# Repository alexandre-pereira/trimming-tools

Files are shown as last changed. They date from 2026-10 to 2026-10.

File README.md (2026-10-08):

# Banc de calage parapente

[English version](README.en.md)

Pour vérifier le calage de sa voile, il faut mesurer chaque suspente sous la même tension.
Ici, deux pièces imprimées en 3D font le travail avec un télémètre laser et une poche à eau
de 5 L : un **banc** qui se pose sur le bord d'une table et tend la suspente à 5 kg, et un
**support de laser** qui coince la patte de la suspente côté voile. Quincaillerie : 30 €.

| Le banc, suspente tendue | Plié : 164 × 93 × 52 mm | Le support du laser et son encoche |
|---|---|---|
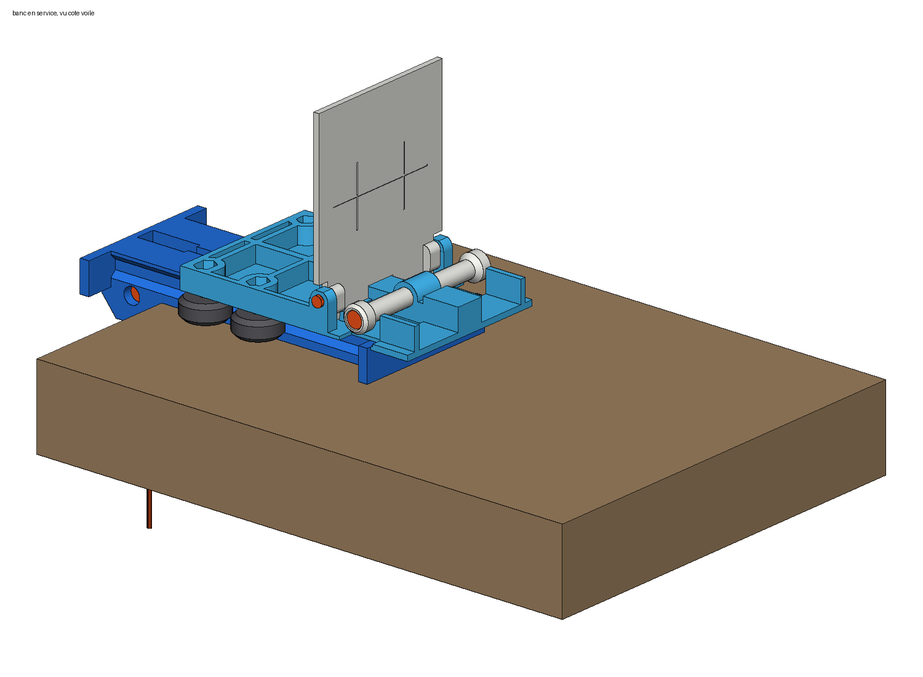
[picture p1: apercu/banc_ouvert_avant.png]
Le banc en service, vu du côté de la voile
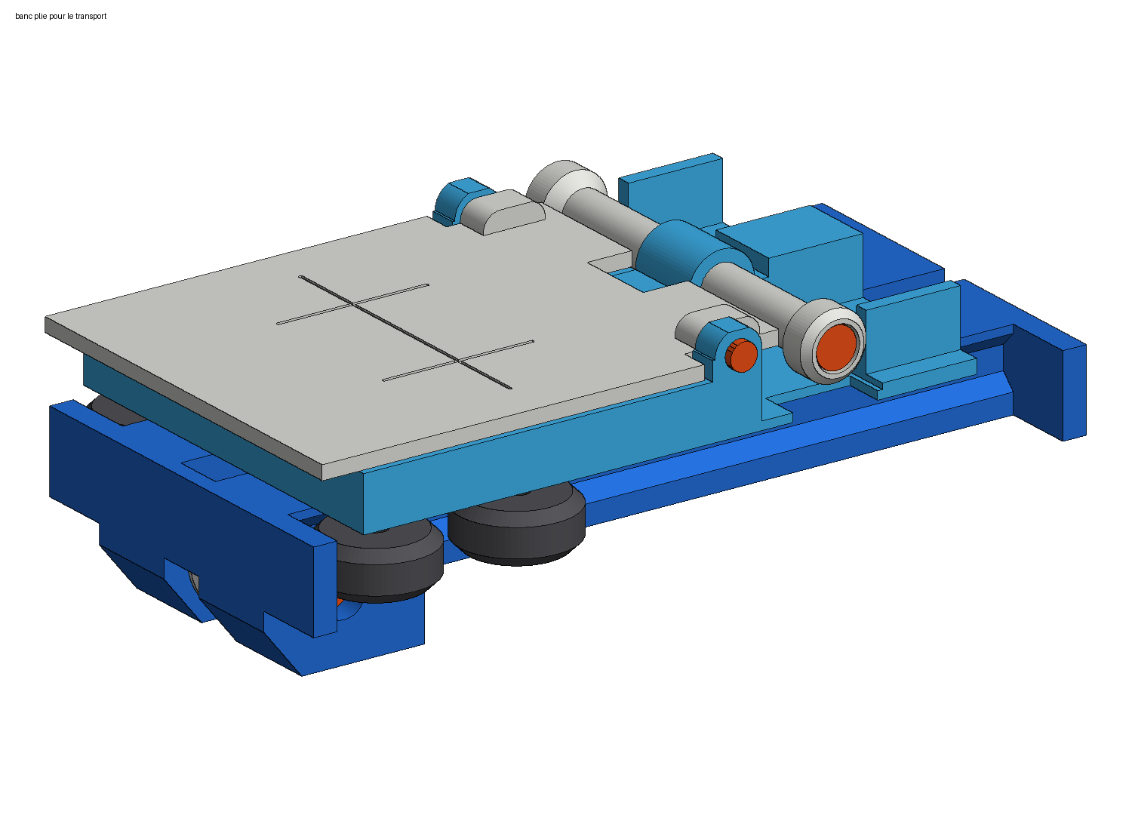
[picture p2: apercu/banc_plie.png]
Le banc plié pour le transport
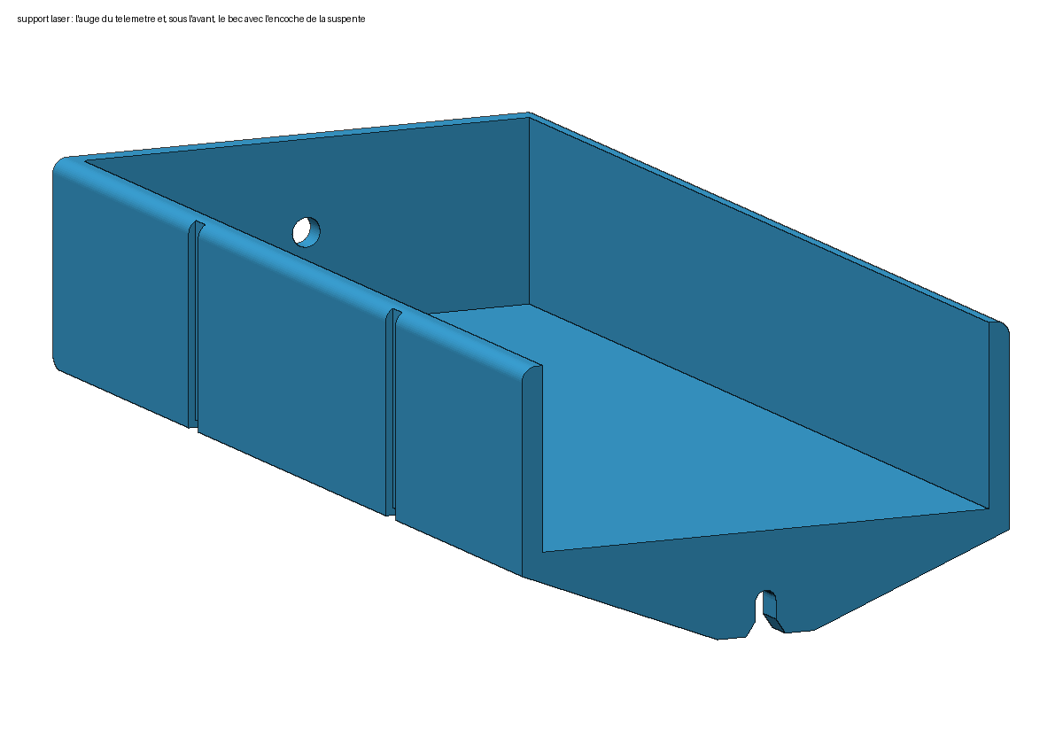
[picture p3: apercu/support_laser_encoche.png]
Le support du télémètre laser, avec l'encoche de la suspente sous l'avant
|  |  |  |

## Comment ça marche

- Le banc s'accroche au bord de la table. Les deux **élévateurs** se posent à plat dessus,
  chacun sur une bobine ; on passe simplement la boucle du maillon par-dessus.
- Un chariot à roulettes relie les élévateurs, par une cordelette et une poulie, à la **poche
  à eau** qui pend sous la table. Tant que le chariot flotte entre ses butées, la suspente est
  tendue à exactement 5 kg.
- Devant les élévateurs, une **cible blanche** se relève et se verrouille d'équerre.
- Côté voile, on glisse la suspente dans l'**encoche du support**, la patte vient en butée,
  et le laser couché dans le support vise la cible. L'outil de calage en ligne fait le reste,
  avec l'offset indiqué plus bas.
- Pour voyager : cible rabattue, un velcro autour.

## Fichiers à imprimer

Sept fichiers pour le banc, un par pièce, déjà orientés pour l'impression, sans support ;
puis le support du laser, dans la version de votre télémètre.

| Fichier | Pièce |
|---|---|
| `socle.stl` | le socle qui s'accroche à la table ([image](apercu/socle.png)) |
| `coulisseau.stl` | le chariot qui porte les élévateurs et la cible ([image](apercu/coulisseau.png)) |
| `cible.stl` | la cible, à imprimer en blanc ([image](apercu/cible.png)) |
| `poulie.stl` | la poulie de la cordelette ([image](apercu/poulie.png)) |
| `bobine_tete.stl`, `bobine_ecrou.stl` | les deux bobines des élévateurs ([image](apercu/bobine_tete.png)) |
| `entretoises_grappe.stl` | 8 petites entretoises sur une barrette, à détacher au cutter ([image](apercu/entretoises_grappe.png)) |

### Le support du laser, à la taille de votre télémètre

Même pièce ([l'encoche](apercu/support_laser_encoche.png), [vue de dessous](apercu/support_laser_bec.png)),
une version par télémètre : les Leica DISTO et les Bosch à moins de 500 €, aux cotes du
constructeur plus 0,5 mm de jeu. Le support est 3 mm moins haut que le télémètre, pour le
saisir et atteindre ses boutons. Certains télémètres ne mesurent que depuis leur face
arrière : leur lecture est plus longue de leur propre longueur, le tableau dit combien
retrancher. GLM 100, 120 et 150 : pointe arrière rentrée.

<!-- supports:debut -->
| Télémètre | Cotes constructeur (mm) | Repère de mesure | Fichier |
|---|---|---|---|
| Leica DISTO D1 | 115 × 43.5 × 23.5 | arrière seulement : retranchez 115 mm de la lecture | `support_laser_leica_d1.stl` ([image](apercu/support_laser_leica_d1.png)) |
| Leica DISTO D110 / E7100i | 120 × 37 × 23 | arrière seulement : retranchez 120 mm de la lecture | `support_laser_leica_d110.stl` ([image](apercu/support_laser_leica_d110.png)) |
| Leica DISTO D2 (v1, 100 m) | 116 × 44 × 26 | avant ou arrière | `support_laser_leica_d2_v1.stl` ([image](apercu/support_laser_leica_d2_v1.png)) |
| Leica DISTO D2 (2025, 150 m) / D2G | 127 × 50.5 × 24.5 | avant ou arrière | `support_laser_leica_d2_2025.stl` ([image](apercu/support_laser_leica_d2_2025.png)) |
| Leica DISTO X1 | 125 × 53.5 × 25.5 | arrière seulement : retranchez 125 mm de la lecture | `support_laser_leica_x1.stl` ([image](apercu/support_laser_leica_x1.png)) |
| Leica DISTO X3 / X4 | 132 × 56 × 29 | avant ou arrière | `support_laser_leica_x3_x4.stl` ([image](apercu/support_laser_leica_x3_x4.png)) |
| Bosch GLM 40 / GLM 30 | 105 × 41 × 24 | avant ou arrière | `support_laser_bosch_glm40.stl` ([image](apercu/support_laser_bosch_glm40.png)) |
| Bosch GLM 50-22 / 50-25 G / 50-27 C / 50-27 CG / 40-31 | 119 × 53 × 29 | avant ou arrière | `support_laser_bosch_glm50.stl` ([image](apercu/support_laser_bosch_glm50.png)) |
| Bosch GLM 80 | 111 × 51 × 30 | avant ou arrière | `support_laser_bosch_glm80.stl` ([image](apercu/support_laser_bosch_glm80.png)) |
| Bosch GLM 100-25 C / 150-27 C / 120 C | 142 × 64 × 28 | avant ou arrière | `support_laser_bosch_glm100_150.stl` ([image](apercu/support_laser_bosch_glm100_150.png)) |
| Bosch Zamo (IV, 2025) | 104 × 38 × 23 | arrière seulement : retranchez 104 mm de la lecture | `support_laser_bosch_zamo.stl` ([image](apercu/support_laser_bosch_zamo.png)) |
| Bosch PLM30-21 / EasyDistance 20 | 94 × 36 × 23 | arrière seulement : retranchez 94 mm de la lecture | `support_laser_bosch_plm30.stl` ([image](apercu/support_laser_bosch_plm30.png)) |
| Bosch PLM40-23 / 50-23 / 60-23C / 70-23C, UniversalDistance 30 / 40C / 50 / 50C, PLR 30 C / 40 C | 100 × 42 × 22 | avant ou arrière | `support_laser_bosch_plm40_70.stl` ([image](apercu/support_laser_bosch_plm40_70.png)) |
| Bosch PLM70-27 / AdvancedDistance 50C / PLR 50 C | 115 × 50 × 23 | avant ou arrière | `support_laser_bosch_plm70_27.stl` ([image](apercu/support_laser_bosch_plm70_27.png)) |
<!-- supports:fin -->

Autre télémètre : mesurez-le (largeur, longueur, épaisseur), reportez les trois cotes dans
`scad/support_laser.scad` et regénérez le STL ; `btn_cote` ouvre une paroi en face de boutons
latéraux.

## Quelle matière

**PETG**, 4 périmètres, 25 % de remplissage, cible en blanc mat. Pas de PLA : il se déforme
dans une voiture au soleil.

Si vous faites imprimer chez [JLC3DP](https://jlc3dp.com/3d-printing-quote) : tout en
**nylon SLS 3201PA-F**, sauf la cible en **résine SLA 9000HE** blanche. Comptez ≈ 44 $ de
pièces pour le banc et ≈ 10 $ de port. Les pièces serrées par des vis ou tirées par
une suspente (socle, chariot, support du laser) ne doivent pas être en résine : elle casse
au lieu de plier.

## Ce qu'il faut acheter

Rien que des vis et des écrous frein, tous sur AliExpress, chez des vendeurs notés. Prix lus
le 5 octobre 2026 (vis M5 × 40, vis et écrous M3 : le 8) ; vérifiez la variante cochée avant
de payer.

| Pièce | Variante à cocher | Il en faut | Prix | Lien |
|---|---|---|---|---|
| Roues V noires Ø 24, roulements montés | « 10PC BigBlack Wheel » | 5 sur 10 | 6,69 € | [annonce](https://fr.aliexpress.com/item/1005003090749056.html) |
| Vis M5 × 25 tête bombée (roues) | « 10Pcs M5x25 » | 4 sur 10 | 4,29 € | [annonce](https://fr.aliexpress.com/item/32850409234.html) |
| Vis M3 × 12 tête bombée (charnière de la cible) | « 30Pcs M3x12 » | 2 sur 30 | 3,69 € | [même annonce](https://fr.aliexpress.com/item/32850409234.html) |
| Vis M5 × 80 tête cylindrique (bobines) | « M5 10 pièces », puis « 80 mm » | 1 sur 10 | 5,09 € | [annonce](https://fr.aliexpress.com/item/32968483467.html) |
| Vis M5 × 40 tête cylindrique (axe de la poulie) | « M5 10 pièces », puis « 40 mm » | 1 sur 10 | 3,09 € | [même annonce](https://fr.aliexpress.com/item/32968483467.html) |
| Écrous frein M5 à bague nylon | « M5 X 50pcs » | 6 sur 50 | 3,39 € | [annonce](https://fr.aliexpress.com/item/1005002375633274.html) |
| Écrous frein M3 à bague nylon | « M3 X 50pcs » | 2 sur 50 | 2,26 € | [même annonce](https://fr.aliexpress.com/item/1005002375633274.html) |
| Cordelette 2 mm | « 10 meters » | 1,5 m | 1,62 € | [annonce](https://fr.aliexpress.com/item/1005011930498059.html) |

**≈ 30 € port compris.** Le roulement de la poulie se récupère sur la cinquième roue, le lest
est votre poche à eau, et il n'y a ni colle ni frein-filet : tout se visse dans des trous
de passage, avec un écrou frein au bout. Le laser n'est pas compté :
un télémètre Bluetooth de 30 m (HOTO QWCJY001 ou équivalent) vaut 30 à 40 €.

### La même chose en Europe

Toute la visserie se trouve à l'unité chez visseriefixations.fr (France). Aucun des sites
européens examinés n'a aussi les roues : elles viennent d'une boutique d'impression 3D. Prix
lus le 8 octobre 2026, port non compris (il ne s'affiche que dans le panier).

| Pièce | Référence du site | Il en faut | Prix | Lien |
|---|---|---|---|---|
| Roues V Ø 24 × 10 en POM, alésage 5, roulements 625ZZ montés | lot de 6 | 5 sur 6 | 12,90 € | [3delectroshop.fr](https://3delectroshop.fr/roulements-et-rotules/504-roulettes-v-slot-en-pom-avec-roulements-625zz.html) |
| Vis M5 × 25 tête bombée, ISO 7380, inox A2 (roues) | TBHC05/025A2 | 4 | 0,08 € pièce | [visseriefixations.fr](https://www.visseriefixations.fr/vis-a-six-pans-creux/tete-bombee-hexagonale-creuse/tbhc-inox-a2-iso-7380/tbhc-m5x25-inox-a2-iso-7380.html) |
| Vis M3 × 12 tête bombée, ISO 7380, inox A2 (charnière de la cible) | TBHC03/012A2 | 2 | 0,05 € pièce | [visseriefixations.fr](https://www.visseriefixations.fr/vis-a-six-pans-creux/tete-bombee-hexagonale-creuse/tbhc-inox-a2-iso-7380/tbhc-m3x12-inox-a2-iso-7380.html) |
| Vis M5 × 40 tête cylindrique, DIN 912, inox A2 (axe de la poulie) | TCHC05/040A2PF | 1 | 0,13 € | [visseriefixations.fr](https://www.visseriefixations.fr/vis-a-six-pans-creux/tete-cylindrique-hexagonale-creuse/inox-a2/tchc-inox-a2-filetage-partiel-din-912/tchc-m5x40-inox-a2-pf-din-912.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) |
| Écrous frein M3 à bague nylon, DIN 985, inox A2 | ECRNYL03A2 | 2 | 0,04 € pièce | [visseriefixations.fr](https://www.visseriefixations.fr/ecrous/ecrous-autofreines/ecrou-hexagonal-autofreine-nylstop/ecrou-nylstop-inox-a2-din-985/ecrou-nylstop-m3-inox-a2-din-985-17062-17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) |
| Écrous frein M5 à bague nylon, DIN 985, inox A2 | ECRNYL05A2 | 6 | 0,04 € pièce | [visseriefixations.fr](https://www.visseriefixations.fr/ecrous/ecrous-autofreines/ecrou-hexagonal-autofreine-nylstop/ecrou-nylstop-inox-a2-din-985/ecrou-nylstop-m5-inox-a2-din-985-99867-99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) |
| Vis M5 × 80 tête cylindrique, DIN 912, inox A2 (bobines) | TCHC05/080A2PF | 1 | 0,59 € | [visseriefixations.fr](https://www.visseriefixations.fr/vis-a-six-pans-creux/tete-cylindrique-hexagonale-creuse/inox-a2/tchc-inox-a2-filetage-partiel-din-912/tchc-m5x80-inox-a2-pf-din-912.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) |

**Visserie : 1,46 €, plus le port ; roues : 12,90 €, plus le port.** La cordelette est
n'importe quelle cordelette de 2 mm.

## Montage

Le schéma complet, avec la visserie : [schema_montage.png](apercu/schema_montage.png).

1. **Poulie** : sortez un roulement d'une roue en trop, emmanchez-le dans la poulie. Posez la
   poulie dans sa fente avec une entretoise de chaque côté. Glissez un écrou frein M5 dans son
   logement, sur un flanc du socle, passez la vis M5 × 40 par l'autre flanc et vissez (clé
   Allen de 4) jusqu'à ce que la tête porte, sans forcer. Tête et écrou restent sous les
   flancs.
2. **Roues** : un écrou frein dans chacun des 4 logements du chariot, puis pour chaque roue
   une vis M5 × 25 par le dessous, à travers la roue et une entretoise.
3. **Jeu** : serrez le côté fixe, poussez les deux autres roues au fond de leur rainure (trous
   oblongs), serrez. Le chariot doit rouler tout seul quand on incline le socle.
4. **Bobines** : sur la vis M5 × 80, une bobine, la nervure du chariot, l'autre bobine, l'écrou
   frein dans le chapeau. On n'y touche plus.
5. **Cible** : glissez un écrou frein M3 dans le logement de chaque oreille du chariot, côté
   intérieur, puis présentez la cible entre les oreilles : elle retient les écrous. De chaque
   côté, vissez une vis M3 × 12 à travers l'oreille (clé Allen de 2) jusqu'à ce que sa tête
   porte. Le bout de la vis sert d'axe à la cible.
6. **Cordelette** : nœud en huit dans le puits derrière la cible ; le brin file dans le canal
   du socle, passe sur la poulie et se noue à la poignée de la poche. Pesez la poche pleine à
   **5,00 kg**.

Réglez la cordelette pour que la poche touche le sol quand la suspente est molle, et décolle
dès qu'on tire.

## Régler l'offset dans l'outil de calage

L'outil demande la distance entre le point d'accrochage de l'élévateur et la cible. Sur le
banc, l'élévateur entier est pris sur la bobine : l'axe de sa vis est à **21 mm** de la face
de la cible, du côté du laser.

**Offset à saisir : 21 mm.**

Réglez le télémètre pour mesurer **depuis sa face avant** : elle affleure le bec du support.

## Pour aller plus loin

- [NOTES.md](https://github.com/alexandre-pereira/trimming-tools/blob/main/NOTES.md) : les
  choix de conception, les cotes, les prix relevés, les variantes écartées et ce qui a été
  vérifié.
- Les modèles OpenSCAD sont dans `scad/`, les scripts qui regénèrent STL, images et ce site
  dans `outils/`. Dépôt : <https://github.com/alexandre-pereira/trimming-tools>, site : <https://trimming-tools.wesoar.fr>.
- Rien n'a encore été imprimé ni essayé sous charge : c'est un modèle, pas un produit testé.

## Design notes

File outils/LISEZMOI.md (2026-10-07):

# Outils de génération

Scripts qui produisent les STL, les images d'aperçu et les schémas de montage.
OpenSCAD n'a pas besoin d'être installé : le rendu passe par sa version WebAssembly.

À lancer depuis ce dossier :

```
npm install openscad-wasm-prebuilt     # une seule fois
node generer_stl.mjs                   # STL dans ../stl, pièces d'assemblage dans ./asm, contrôles d'interférence
python render2.py                      # une image par STL + vues d'assemblage, dans ../apercu
python schema.py                       # schémas de montage avec la visserie, dans ../apercu
```

Python a besoin de `numpy` et `Pillow`. Les positions de la visserie dans `schema.py`
reprennent les cotes de `../scad/banc.scad` : si le modèle change, les mettre à jour.

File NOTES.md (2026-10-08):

# Notes de conception du banc de calage

Ce document rassemble le détail : choix de conception, cotes, prix relevés, vérifications,
variantes écartées. La présentation courte est dans [README.md](README.md).

Un petit bloc imprimé qui se pose sur le bord d'une table, sur le principe de l'EasyTrim :
il met la suspente sous 5 kg et présente une cible au télémètre laser. La cible se rabat
à plat pour le transport.

| En service | Plié |
|---|---|
| banc ouvert | banc plié |

Autres vues : [côté poche à eau](apercu/banc_ouvert_arriere.png),
[profil ouvert](apercu/banc_ouvert_profil.png), [profil plié](apercu/banc_plie_profil.png).

## Principe

- Le **socle** s'accroche au chant de la table par deux crochets. Aucune fixation : c'est la
  tension de la suspente qui le plaque contre le bord.
- La **poulie** tourne sur un roulement à billes, autour d'une vis M5 qui traverse
  les deux crochets. Elle est logée dans le bloc des crochets, sous le passage du
  coulisseau : la cordelette monte de la poche à eau, passe sur la poulie et rejoint le
  coulisseau par un canal creusé dans le dessus du socle. Rien ne dépasse du socle, et les
  rainures des roues passent au-dessus des crochets : c'est ce qui rend le banc court.
- Les **fins de course** sont deux butées relevées aux deux bouts du socle, contre lesquelles
  les roues s'arrêtent. Le coulisseau ne peut pas sortir de ses rainures.
- Le **coulisseau** roule sur le socle par 4 roues à gorge en V montées sur des vis M5.
  Les roues s'engagent dans deux rainures en V taillées dans les flancs du socle : le
  coulisseau ne peut ni se soulever ni se mettre de travers.
- Les **élévateurs** s'accrochent à l'avant du coulisseau, posés à plat, chacun sur une
  bobine, de part et d'autre d'une nervure centrale. La boucle de base de l'élévateur se
  passe par-dessus le chapeau de la bobine, sans rien dévisser, puis la sangle se couche
  dans son couloir, entre la nervure et une joue : elle ne peut pas glisser de côté. Rien ne
  se démonte à l'usage, donc rien ne se perd, et la sangle ne touche que du plastique lisse
  (la vis qui porte les bobines est noyée dedans). La traction passe par tout l'élévateur,
  comme en vol.
- La **cible** est articulée à l'avant du coulisseau, juste derrière les bobines. Relevée et
  poussée vers le bas, sa languette se coince entre la face avant du coulisseau et une lèvre
  inclinée : elle est verrouillée d'équerre et ne peut basculer ni en avant ni en arrière.
  Pour la rabattre, on la soulève de 5,5 mm puis on la couche sur le coulisseau. Une mire
  gravée indique où viser.
- Côté voile, le **support du laser** coince la patte d'attache dans l'encoche de son bec, et
  le laser couché dedans vise la cible. **Longueur = lecture + constante**, la constante
  étant étalonnée une fois.

Quand le coulisseau flotte entre ses deux butées, la suspente est tendue au poids de la
poche. Deux choses pourraient fausser cette tension, et le banc est dessiné pour les rendre
négligeables :

- **le frottement de la poulie** : elle tourne sur un roulement à billes, pas sur un simple
  axe (un axe lisse dans du plastique mangerait de l'ordre de 10 % de la tension, dans un
  sens puis dans l'autre) ;
- **l'inclinaison de la cordelette** : la poulie étant sous le coulisseau, le brin monte de
  6 mm jusqu'à son attache. Celle-ci est placée le plus en avant possible du coulisseau, si
  bien que la tension réelle vaut 99,2 % du poids en butée arrière, 99,8 % à mi-course et
  99,9 % en fin de course (calcul géométrique, non mesuré).

## Encombrement

| | Longueur | Largeur | Épaisseur |
|---|---|---|---|
| Plié | 164 mm | 93 mm | 52 mm (dont 14 mm de crochets) |
| En service | 164 mm, plus l'avancée du coulisseau | 93 mm | 136 mm |

Course du coulisseau : 100 mm. La longueur du banc vaut course + entraxe des roues + 34 mm
(un diamètre de roue et les deux butées de 5 mm) ; les 34 mm de crochets devant la table sont
compris, puisque les rainures passent au-dessus. On peut échanger course et entraxe dans
`banc.scad` :

| Entraxe des roues (`wheel_px`) | Course (`travel`) | Longueur du banc |
|---|---|---|
| **30 mm (réglage actuel)** | **100 mm** | **164 mm** |
| 40 mm | 100 mm | 174 mm |
| 30 mm | 150 mm | 214 mm |

Au repos et plié, tout tient dans la longueur du socle : le coulisseau (130 mm) reste
au-dessus, et la cible rabattue ne dépasse pas à l'arrière. En bout de course côté voile,
l'avant du coulisseau dépasse du socle de 75 mm, au-dessus de la table.

L'entraxe de 30 mm est le plus court raisonnable : en dessous de 28 mm, les roues se
toucheraient. Un entraxe court guide un peu moins bien le coulisseau quand un seul élévateur
tire, donc de travers ; si cela se voit à l'usage, repasser à 40 mm coûte 10 mm de longueur.

Deux variantes plus courtes ont été essayées puis écartées :

- 149 mm, roues fixées sur le socle et coulisseau en tiroir : plus épaisse de 8 mm,
  coulisseau en deux pièces qui dépasse derrière la table au repos. Son modèle reste dans
  `scad/banc_149mm.scad`, sans STL.
- 146 mm, sans butées en bout de socle, le coulisseau étant arrêté par une goupille circulant
  dans le canal de la cordelette. Non conservée.

## Pièces imprimées (`stl/`)

| Fichier | Pièce | Aperçu | Volume |
|---|---|---|---|
| `socle.stl` | socle, butées, crochets de table, logement de la poulie, canal de la cordelette | [image](apercu/socle.png) | 101 cm³ |
| `coulisseau.stl` | plaque mobile, couloirs des élévateurs, lèvre de verrouillage, oreilles de charnière | [image](apercu/coulisseau.png) | 58 cm³ |
| `poulie.stl` | poulie Ø25, avec le logement du roulement 625 | [image](apercu/poulie.png) | 2 cm³ |
| `cible.stl` | cible articulée 84 × 101, avec mire gravée | [image](apercu/cible.png) | 25 cm³ |
| `bobine_tete.stl` | bobine dont le chapeau loge la tête de vis | [image](apercu/bobine_tete.png) | 2 cm³ |
| `bobine_ecrou.stl` | bobine dont le chapeau loge l'écrou frein | [image](apercu/bobine_ecrou.png) | 2 cm³ |
| `entretoises_grappe.stl` | les 8 entretoises (4 pour les roues, 2 pour la poulie, 2 de rechange) réunies par une barrette, à détacher au cutter | [image](apercu/entretoises_grappe.png) | 1 cm³ |
| `support_laser_<modèle>.stl` | support du télémètre, côté voile, avec son bec à encoche ; une version par télémètre | [en service](apercu/support_laser_arriere.png), [le bec](apercu/support_laser_bec.png) | ≈ 20 à 50 cm³ |

Une pièce par fichier, chaque fichier à imprimer une fois ; seules les entretoises sont
groupées, parce qu'un service d'impression refuse les pièces minuscules.

Toutes sortent orientées pour l'impression, sans support : socle dessus contre le plateau,
coulisseau dessous contre le plateau, cible dos contre le plateau, poulie à plat, bobines
debout sur leur tube, entretoises à plat, support du laser debout sur la face avant de son
bec.

Pour un objet qui voyage : PETG (ou ASA), 4 périmètres, 25 % de remplissage. Cible en blanc
mat de préférence.

Les modèles paramétriques sont `scad/banc.scad` (variable `part` pour choisir la pièce,
`plie = true` pour voir l'assemblage rabattu) et `scad/support_laser.scad`.

## Support du laser

Repris de votre « TEST.stl », même principe : le télémètre est couché dans une auge ouverte
à l'avant ; sous l'avant, un bec plat descend sous le fond et porte une encoche. On y glisse
la suspente par en dessous, sa patte d'attache (ou son nœud), trop grosse, bute contre le
bec : sous 5 kg, la suspente reste dans l'axe du faisceau. Vues :
[en service, vu de l'arrière](apercu/support_laser_arriere.png), [le bec](apercu/support_laser_bec.png).

- **Cotes du télémètre en paramètres** : `laser_w`, `laser_l`, `laser_h` (largeur, longueur,
  épaisseur), à mesurer au pied à coulisse. Les valeurs par défaut (34,5 × 78,5 × 18 mm) sont
  celles de votre TEST.stl, pas celles d'un télémètre précis : les remplacer par les vôtres.
- **Moins épais que le télémètre** : les parois s'arrêtent `moins_epais` (3 mm) sous le dessus
  du télémètre, pour le saisir et atteindre ses boutons.
- **Boutons sur le côté** : `btn_cote` (0 aucun, 1 droite, -1 gauche, 2 les deux) abaisse la
  paroi en face des boutons, entre `btn_y0` et `btn_y0 + btn_len` depuis la face arrière du
  télémètre, en ne laissant que `btn_h` (4 mm) de paroi.
- **Encoche** : 3 mm de large (`slit_w`), entrée en V, fond rond : toutes les suspentes
  passent, la patte d'attache ou son nœud non. Le bec garde la forme et l'épaisseur (4 mm)
  de TEST.stl ; une première version avec une bande de renfort derrière le bec a été
  retirée le 7 octobre 2026 : elle débordait sous le fond.
- **Offset** : l'outil de calage attend la distance entre l'axe d'accrochage de l'élévateur
  et la cible. L'élévateur entier est pris sur la bobine ; la face visée de la cible
  (`sl_front + tg_t` = 51) est 21 mm derrière l'axe des bobines (`sl_front + pin_x` = 72),
  vu du laser. Offset = 21 mm, le télémètre réglé « mesure depuis l'avant » (sa face avant
  affleure le bec, au jeu `fit` près).
- **Versions** : une par télémètre de `outils/lasers.json` (Leica DISTO et Bosch à moins de
  500 €, cotes constructeur) ; `node outils/generer_stl.mjs lasers` regénère les STL et le
  tableau du README.
- Deux rainures pour un élastique qui tient le télémètre, un trou de dragonne dans la face
  arrière, 21 cm³.

**Matière recommandée : PETG** (ou ASA) sur votre imprimante ou au fablab, 4 périmètres,
25 % de remplissage, comme le reste du banc. Chez JLC3DP : **nylon 3201PA-F**. Pas de résine
pour cette pièce : le bec travaille en tension et prend des chocs, et la résine casse au
lieu de plier.

## Ce qu'il faut acheter

Prix indicatifs relevés en ligne ou estimés ; à vérifier au moment de la commande.

| Pièce et dimensions | Qté (1 banc / 10) | Prix relevé | Lien |
|---|---|---|---|
| Roue V pour profilé V-slot, POM, Ø 24 × 10,2 mm, alésage 5 mm, 2 roulements 625ZZ montés | 4 / 40 | 12,90 € le lot de 6 | [3delectroshop.fr](https://3delectroshop.fr/roulements-et-rotules/504-roulettes-v-slot-en-pom-avec-roulements-625zz.html) ; par lots : [AliExpress](https://fr.aliexpress.com/item/1005001588321075.html) |
| Vis à tête bombée six pans creux M5 × 25, ISO 7380, filetée sur toute la longueur, tête Ø 9,5 × 2,75 mm, clé de 3 (roues) | 4 / 40 | 0,08 € pièce | [visseriefixations.fr](https://www.visseriefixations.fr/vis-a-six-pans-creux/tete-bombee-hexagonale-creuse/tbhc-inox-a2-iso-7380/tbhc-m5x25-inox-a2-iso-7380.html) |
| Roulement à billes 625ZZ, 5 × 16 × 5 mm (poulie) | 1 / 10 | 0 € pour un banc : le prendre sur une des 2 roues en trop du lot de 6 ; sinon 1,10 € pièce | [reprap-france.com](https://www.reprap-france.com/produit/1234568282-roulement-a-billes-625zz) |
| Vis à tête cylindrique six pans creux M5 × 40, DIN 912, tête Ø 8,5 × 5 mm, clé de 4, tige lisse sur ≈ 18 mm (axe de poulie) | 1 / 10 | 0,13 € pièce | [visseriefixations.fr](https://www.visseriefixations.fr/vis-a-six-pans-creux/tete-cylindrique-hexagonale-creuse/inox-a2/tchc-inox-a2-filetage-partiel-din-912/tchc-m5x40-inox-a2-pf-din-912.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) |
| Vis à tête cylindrique six pans creux M5 × 80, DIN 912, tête Ø 8,5 × 5 mm, clé de 4 (bobines) | 1 / 10 | 0,59 € pièce | [visseriefixations.fr](https://www.visseriefixations.fr/vis-a-six-pans-creux/tete-cylindrique-hexagonale-creuse/inox-a2/tchc-inox-a2-filetage-partiel-din-912/tchc-m5x80-inox-a2-pf-din-912.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) |
| Écrou frein à bague nylon M5, DIN 985, 8 mm sur plats, hauteur 5 mm (roues, bobines et poulie) | 6 / 60 | 0,04 € pièce | [visseriefixations.fr](https://www.visseriefixations.fr/ecrous/ecrous-autofreines/ecrou-hexagonal-autofreine-nylstop/ecrou-nylstop-inox-a2-din-985/ecrou-nylstop-m5-inox-a2-din-985-99867-99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) |
| Vis à tête bombée six pans creux M3 × 12, ISO 7380, tête Ø 5,7 × 1,65 mm, clé de 2 (charnières) | 2 / 20 | 0,05 € pièce | [visseriefixations.fr](https://www.visseriefixations.fr/vis-a-six-pans-creux/tete-bombee-hexagonale-creuse/tbhc-inox-a2-iso-7380/tbhc-m3x12-inox-a2-iso-7380.html) |
| Écrou frein à bague nylon M3, DIN 985, 5,5 mm sur plats, hauteur 4 mm (charnières) | 2 / 20 | 0,04 € pièce | [visseriefixations.fr](https://www.visseriefixations.fr/ecrous/ecrous-autofreines/ecrou-hexagonal-autofreine-nylstop/ecrou-nylstop-inox-a2-din-985/ecrou-nylstop-m3-inox-a2-din-985-17062-17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) |
| Cordelette Ø 2 mm, longueur 1,5 m | 1 / 10 | 0 € | reste de suspente, drisse, paracorde |
| Lest de 5 kg | 1 / — | 0 € | votre poche à eau, ou un bidon d'eau de 5 L à poignée |
| Sangle velcro 20 mm | — | 0 € | fonds de tiroir |
| **Visserie d'un banc** | | **1,46 €, hors port** | |
| Impression des 7 fichiers du banc et du support (≈ 210 cm³, ≈ 130 g de PETG ; plus grande pièce 164 × 80 × 31 mm) | 1 / 10 | 5–25 € | fablab, ou [devis JLC3DP](https://jlc3dp.com/3d-printing-quote) |
| Télémètre Bluetooth HOTO QWCJY001, 99,5 × 44,1 × 23,3 mm, 30 m, ±2 mm | 1 | 35–39 € | [ulen.eu](https://ulen.eu/fr/product/hoto-qwcjy001-telemetre-laser-bluetooth/), [domotique-store.fr](https://www.domotique-store.fr/maison/outillage/4240-metre-laser-intelligent-bluetooth-hoto-qwcjy001.html), [AliExpress](https://www.aliexpress.com/i/1005002004493544.html) |

Prix relevés sur les pages produit le 4 octobre 2026, ceux de la visserie et des roues relus
le 8 ; les frais de port ne sont pas vérifiés (ils ne s'affichent que dans le panier).
Le lot de 5 roues d'aboutfilament.fr (8,49 €) était en rupture le 4 ; celui de
3delectroshop.fr était en stock le 8 (4 lots).

**Toute la visserie sur un seul site européen : visseriefixations.fr**, à l'unité, sans
minimum de commande affiché. Recherche du 8 octobre 2026 sur une douzaine de sites :

- **Aucun des sites examinés n'a à la fois les roues V et la visserie à l'unité.** Il faut
  deux commandes.
- **bricovis.fr** a les mêmes références aux mêmes prix : c'est l'équivalent exact.
- **vis-express.fr** a tout aussi, nettement plus cher.
- Stock immédiat lu le 8 octobre : 350 vis M5 × 40 et 7 898 écrous frein M3 ; celui des vis
  M3 × 12 ne s'est pas affiché.
- La vis M5 × 25 peut y être livrée en filetage total ou partiel, la norme ne le fixant
  pas : les deux conviennent, l'écrou est au bout. La M5 × 80 n'existe qu'en filetage partiel
  (≈ 22 mm), ce qui convient aussi.
- Autre source de roues : roboter-bausatz.de, lot de 5 à 7,39 € (Ø 23,89 × 10,23, roulements
  625ZZ), mais 14,99 € de port vers la France.

Le chemin le moins cher : roues sur AliExpress (≈ 3 €), la visserie à l'unité en
quincaillerie (≈ 4 €), impression dans un fablab (≈ 5 €), cordelette et lest de récupération,
soit **≈ 12 € de banc**, plus le télémètre (≈ 25 € en promotion).

Ce qui a fait baisser la facture :

- **Le roulement de la poulie ne coûte rien** pour un seul banc : les roues se vendent par
  lot de 6, il en reste deux, et chacune contient deux roulements 625 qui se chassent à la
  main ou avec une vis.
- **L'axe de poulie est une vis M5 × 40** et son écrou frein, noyés dans les crochets.
- **Plus aucune rondelle à acheter** : les rondelles M5 sont remplacées par 6 entretoises
  imprimées (4 pour les roues, 2 pour la poulie), fournies dans `entretoises_grappe.stl` avec
  deux de rechange ; la
  rondelle M4 du nœud est supprimée.
- **Charnière sur deux vis M3 × 12** et leurs écrous frein, et **bobines sans rondelle**.
- **Ni colle ni frein-filet** : partout une vis dans un trou de passage et un écrou frein
  au bout.
- **Pas de mousqueton ni de Dyneema neuve** : n'importe quelle cordelette de 2 mm tient 5 kg ;
  elle se noue directement à la poignée du lest.
- **Lest** : la poche à eau que vous avez déjà, ou un bidon d'eau du commerce.
- **Socle évidé** par-dessous.

Ce qui reste cher, et pourquoi je n'y ai pas touché :

- **Le télémètre** pèse plus que tout le banc. Je n'ai pas trouvé de modèle Bluetooth vérifié
  moins cher que le HOTO ; les modèles à 12–18 € n'ont pas le Bluetooth. Il est vu de
  21 $ (promotion Amazon aux États-Unis) à 38 $ sur AliExpress : surveiller les promotions.
- **L'impression par un service en ligne** : c'est le port, plus que le plastique, qui fait
  le prix. Un fablab ou une imprimante prêtée ramène ce poste à ≈ 5 €.

### Tout acheter sur AliExpress : annonces qui ont des avis

Relevé du 5 octobre 2026 (vis M5 × 40, vis et écrous M3 : du 8). Pour chaque annonce, j'ai lu la note, le nombre
d'avis et les variantes que les acheteurs ont notées. **Vérifiez sur la page que la taille
existe et notez le prix** avant de commander.

| Pièce | Variante à choisir | Qté pour 1 banc | Avis | Lien |
|---|---|---|---|---|
| Roue V noire en POM, Ø 23,9 × 10,23 mm, alésage 5 mm, avec ses 2 roulements 625 | « 10PC BigBlack Wheel » (lot de 10) | 5 (4 roues + 1 pour le roulement de la poulie) | 4,9 / 5 sur 88 avis, dont 46 sur cette variante | [roues, lot de 10](https://fr.aliexpress.com/item/1005003090749056.html) |
| Vis à tête bombée six pans creux ISO 7380, inox, M5 × 25 (roues) | « 10Pcs M5x25 » | 4 | 4,8 / 5 sur 64 avis, dont 2 sur cette variante | [vis tête bombée M3 à M5](https://fr.aliexpress.com/item/32850409234.html) |
| Vis à tête bombée six pans creux ISO 7380, inox, M3 × 12 (charnières) | « 30Pcs M3x12 » | 2 | même annonce, 3 avis sur cette variante | [vis tête bombée M3 à M5](https://fr.aliexpress.com/item/32850409234.html) |
| Vis à tête cylindrique six pans creux DIN 912, inox 304, M5 × 80 (bobines) | « M5 10 pièces », longueur « 80 mm » | 1 | 4,9 / 5 sur 1 535 avis | [vis DIN912 HZYUEGOU](https://fr.aliexpress.com/item/32968483467.html) |
| Vis à tête cylindrique six pans creux DIN 912, inox 304, M5 × 40 (axe de poulie) | « M5 10 pièces », longueur « 40 mm » | 1 | même annonce, 5 avis sur cette variante parmi les 400 derniers | [vis DIN912 HZYUEGOU](https://fr.aliexpress.com/item/32968483467.html) |
| Écrou frein à bague nylon DIN 985, inox 304, M5 | « M5 X 50pcs » | 6 | 5,0 / 5 sur 22 avis, dont 3 sur cette variante | [écrous frein M2 à M20](https://fr.aliexpress.com/item/1005002375633274.html) |
| Écrou frein à bague nylon DIN 985, inox 304, M3 | « M3 X 50pcs » | 2 | même annonce, 5 avis sur cette variante | [écrous frein M2 à M20](https://fr.aliexpress.com/item/1005002375633274.html) |
| Cordelette de 2 mm (paracorde à une âme) | « 10 meters », couleur au choix | 1,5 m | 4,9 / 5 sur 108 avis | [paracorde 2 mm](https://fr.aliexpress.com/item/1005011930498059.html) |

Les goupilles des relevés précédents ont disparu de la liste : voir « Des vis et des écrous,
plus de goupilles ». Les trois lignes ajoutées viennent des annonces déjà retenues, donc sans
port supplémentaire.

La même liste, à cocher, est sur une page à part : <https://claude.ai/artifact/KuYeWNqA6emn3GKmHpZLea>
(page privée, ouverte avec votre compte Claude).

**Prix lus sur les annonces le 5 octobre 2026**, dans le navigateur, sans compte, pour une
livraison en France :

| Ligne | Prix lu |
|---|---|
| Roues « 10PC BigBlack Wheel », lot de 10 | 6,69 € |
| Vis M5 × 25 tête bombée, lot de 10 | 4,29 € |
| Écrous frein M5, lot de 50 | 3,39 € |
| Vis M5 × 80, lot de 10 | 5,09 € |
| Cordelette 2 mm, 10 m | 1,62 € |
| Vis M5 × 40, lot de 10 (lu le 8 octobre) | 3,09 € |
| Vis M3 × 12 tête bombée, lot de 30 (lu le 8 octobre) | 3,69 € |
| Écrous frein M3, lot de 50 (lu le 8 octobre) | 2,26 € |
| **Quincaillerie, tout compris** | **30,12 €**, livraison gratuite (articles « Choice », plus de 10 €) |

Une réserve :

- **Télémètre** : l'annonce HOTO que j'avais retenue n'est plus vendue en France (page
  introuvable). Une recherche montre un télémètre du même format à 29,39 €, noté 4,8, que je
  n'ai pas vérifié (marque, Bluetooth). Les revendeurs européens du tableau plus haut
  restent valables, à 35–39 €.

- **Roulement de la poulie** : il se prend sur la cinquième roue du lot de 10.
- **Sur les roues**, vérifiez à réception la largeur sur les deux roulements : le modèle
  compte 11 mm (paramètre `wheel_stack`).

### Prises de filet vérifiées

Calculées sur le modèle, vis par vis.

| Vis | Empilage sous la tête | Écrou | Bout de la vis |
|---|---|---|---|
| M5 × 25 des roues (×4), filetée sur toute la longueur | roue 11,0 (sur ses deux roulements) + entretoise 2,7 + coulisseau 5,3 = 19,0 mm | frein de 5 mm : de 19,0 à 24,0 | dépasse l'écrou de 1 mm (bague nylon en prise), reste 0,2 mm sous le dessus du coulisseau |
| M5 × 80 des bobines (×1) | bobine 29,25 + nervure 16 + bobine 28,25 = 73,5 mm | frein de 5 mm : de 73,5 à 78,5 | dépasse l'écrou de 1,5 mm (bague nylon en prise), reste 0,5 mm à l'intérieur du chapeau |
| M5 × 40 de la poulie (×1) | d'un fond de logement à l'autre : 50 − 9,5 − 6,5 = 34,0 mm | frein de 5 mm : de 34,0 à 39,0 | dépasse l'écrou de 1 mm (bague nylon en prise), reste 0,5 mm sous le flanc |
| M3 × 12 des charnières (×2) | 2,0 mm d'oreille | frein de 4 mm, logé dans l'oreille : de 2,0 à 6,0 | dépasse l'écrou de 6 mm : 0,4 mm de jeu, puis 5,6 mm dans la lumière du charnon, profonde de 6,5 |

**La vis des roues doit être filetée sur toute sa longueur, et ce n'est pas une erreur.**
L'écrou est tout au bout, donc il faut du filet au bout ; et en M5 × 25, les vis ISO 7380
n'existent qu'entièrement filetées. Les deux roulements de la roue reposent donc sur le
filet, ce qui ne gêne pas : leurs bagues intérieures sont serrées entre la tête de vis et
l'entretoise, elles ne tournent pas sur la vis. C'est le montage d'origine de ces roues
(OpenBuilds). La poulie tourne sur son roulement, la cible sur le bout de ses vis M3.

Il faut du filet sur les 7 derniers millimètres de la M5 × 80 : une DIN 912 normale en a 22.

Deux corrections sont sorties de cette vérification :

- le modèle comptait 10,23 mm pour la roue au lieu de 11 mm sur ses roulements, et la vis ne
  prenait qu'une partie de l'écrou ;
- pour se passer de frein-filet, les roues sont maintenant tenues par des écrous frein. Il a
  fallu une vis de 25 mm au lieu de 20 et un coulisseau de 11,5 mm au lieu de 8.

### Aucune colle

| Assemblage | Ce qui le tient |
|---|---|
| Roues | écrou frein à bague nylon, noyé dans un logement à six pans du coulisseau |
| Bobines des élévateurs | écrou frein noyé dans un chapeau |
| Charnières de la cible | vis M3 × 12 bloquée sur l'oreille, entre sa tête et un écrou frein logé dans la face intérieure ; le charnon voisin empêche l'écrou de ressortir |
| Axe de poulie | vis M5 × 40 et écrou frein, noyés dans les deux crochets |
| Roulement dans la poulie | emmanché dans son logement, retenu par une lèvre |

### Des vis et des écrous, plus de goupilles

Deux systèmes de goupilles ont été essayés puis abandonnés le 8 octobre 2026, parce que leur
tenue restait trop aléatoire :

- des goupilles lisses serrées dans des trous à six pans : le serrage se jouait à 0,05 mm,
  moins que la précision d'une imprimante ;
- des goupilles cannelées DIN 1472 dans des trous ronds : plus tolérantes, mais leur tenue
  dépendait encore du diamètre sorti de l'imprimante, qu'un calibre imprimé devait régler.

Le banc n'a plus que des vis dans des trous de passage (Ø 5,3 pour le M5, Ø 3,3 pour le M3),
chacune arrêtée par un écrou frein à bague nylon. Rien ne dépend plus d'un ajustement : un
trou sorti un peu grand ou un peu petit ne change rien à la tenue.

- **Poulie** : vis M5 × 40 à tête cylindrique. Sa tête (logement Ø 9, profond de 9,5 mm) et
  son écrou frein (logement à six pans, profond de 6,5 mm) sont noyés dans les crochets,
  parce que les roues passent le long des flancs. Le roulement tourne autour de la vis,
  entre ses deux entretoises ; avec une vis à filetage partiel, il porte sur la tige lisse.
- **Charnières** : vis M3 × 12 à tête bombée. La tête porte sur le flanc de l'oreille, et
  l'écrou frein est logé dans sa face intérieure : la vis est bloquée sur l'oreille, et les
  5,6 mm qui dépassent de l'écrou servent d'axe à la cible, dans la lumière du charnon. Le
  charnon, à 0,4 mm de l'oreille, empêche l'écrou de ressortir. La cible tourne et coulisse
  donc sur un bout fileté : c'est moins doux que sur une tige lisse, sans conséquence pour
  une charnière qui ne bouge qu'au pliage.
- Les oreilles ont pris 1 mm de rayon pour loger l'écrou, et leur dessus est arasé 4,5 mm
  au-dessus de l'axe : le banc plié reste à 52 mm. Les têtes des vis de charnière dépassent
  de 1,65 mm de chaque côté, moins que les roues.
- L'axe de la poulie est 1 mm sous le dessus de la table : le logement de la tête de vis
  passe ainsi sous les rainures en V sans amincir le chanfrein où roule la roue.
- Les logements d'écrou ont deux pans horizontaux : ils s'impriment sans support.

Rien de tout cela n'a été imprimé.

### Contrôle avant impression (8 octobre 2026)

Fait sur les fichiers de `stl/`, par calcul : aucun essai, aucune pièce imprimée.

- **Maillages** : les 21 fichiers sont fermés et orientés de façon cohérente.
- **Interférences** : les 14 contrôles de `generer_stl.mjs check` (banc ouvert et plié,
  coulisseau aux deux bouts de sa course) ne trouvent aucun volume commun ; il ne reste que
  les contacts voulus (roues dans leurs rainures, cible contre la face avant, bobines contre
  la nervure).
- **Impression sans support** : le plus long pontage est le fond du canal de la cordelette
  (6 mm) ; viennent ensuite les lumières de la cible (6,1 mm) et les logements d'écrou (4,8
  et 3,35 mm).
- **Parois** : aucune sous 1,2 mm dans le socle ni dans le coulisseau (1,77 et 1,60 mm au
  plus mince). La cible a une cloison de 1,0 mm au fond de chaque lumière, sans rôle
  mécanique ; le chapeau de `bobine_ecrou` descend à 0,7 mm aux angles de son logement
  d'écrou, sur le dernier 1,5 mm, au-dessus de l'écrou.
- **Efforts sous 5 kg** (49 N dans la suspente, 69 N sur l'axe de la poulie), par calcul à
  la main, section par section :

| Endroit | Contrainte calculée |
|---|---|
| Crochets contre le chant de la table | 0,1 MPa |
| Portée de la vis de poulie dans les crochets | 0,7 MPa |
| Matière sous la vis de poulie, au-dessus de l'évidement du crochet | ≈ 2,5 MPa |
| Ailes des butées, coulisseau retenu par les 5 kg | 3,3 MPa |
| Lèvres des rainures sous les roues | ≈ 1,6 MPa |
| Nervure du coulisseau autour de la vis des bobines | 0,6 MPa |
| Vis M5 × 80 des bobines, en flexion (acier) | 46 MPa |
| Vis M5 × 40 de la poulie, en flexion (acier) | 26 MPa |

  Le PETG imprimé casse vers 45 MPa dans le plan des couches et vers 25 MPa entre couches ;
  sous charge permanente, mieux vaut rester sous 5 à 10 MPa. L'inox A2-70 plie à 450 MPa.
  Les pièces sont donc chargées au tiers de cette limite prudente au pire endroit, et bien
  moins ailleurs.
- **Basculement** : le banc tient sur la table par la traction de la suspente. À
  l'horizontale, le moment qui le plaque vaut 1,7 fois celui de la poche à eau. Si la
  suspente monte vers la voile, la marge fond : au-delà de ≈ 6° (10 cm par mètre), coulisseau
  en bout de course, l'avant du banc se soulève.

### Télémètre Bluetooth le moins cher

- **HOTO QWCJY001** (écosystème Xiaomi) : Bluetooth, 30 m, ±2 mm, 99,5 × 44,1 × 23,3 mm,
  recharge USB-C. Vu entre 25 € (AliExpress) et 35–39 € chez des revendeurs européens.
  Les mesures remontent dans l'application Mi Home ; je n'ai pas pu vérifier si elle sait
  exporter une liste de mesures.
- **Mileseey D5T** : Bluetooth, 50 m, ±2 mm, 110 × 50 × 26 mm, application dédiée ;
  vu de 25 à 45 € selon les vendeurs.
- **À éviter pour cet usage** : le Duka LS-P (15–18 €), très bon marché mais sans Bluetooth.
- Quel que soit le télémètre, ses trois cotes se reportent dans `scad/support_laser.scad`.

### Où faire imprimer

- **Fablab ou atelier partagé près de chez vous** : on ne paie en général que la matière et
  une adhésion, soit 5 à 10 € de PETG. Le plus économique et le plus rapide pour corriger.
  Demander du PETG (ou de l'ASA), 4 périmètres, 25 % de remplissage, et la cible en blanc.
- **JLC3DP** (Chine, devis instantané) : voir ci-dessous.
- **Craftcloud** (comparateur d'All3DP) : met en concurrence des imprimeurs, dont des
  européens ; plus rapide, plus cher.

### Commander chez JLC3DP : quelle matière pour quelle pièce

JLC3DP ne propose pas de PETG. En dépôt de fil (FDM), il a du PLA, de l'ABS, de l'ASA, du
PA12-CF et du TPU ; en frittage de poudre (SLS), plusieurs nylons. Relevé sur ses pages d'aide
le 5 octobre 2026.

| Fichier | Procédé et matière | Couleur | Pourquoi |
|---|---|---|---|
| `socle.stl`, `coulisseau.stl` | SLS, nylon 3201PA-F | gris-noir | pièces de structure ; le nylon est tenace (35 % d'allongement) et n'a pas de sens de couche |
| `poulie.stl`, `bobine_tete.stl`, `bobine_ecrou.stl`, `entretoises_grappe.stl` | SLS, nylon 3201PA-F | gris-noir | trop petites pour le FDM de JLC3DP (taille minimale 30 × 30 × 15 mm en ASA) |
| `cible.stl` | SLA, résine 9000HE ; ou SLS, nylon Precimid 1172 Pro (≈ 5 $ de plus, grain mat, tient la chaleur) | blanc | elle doit être blanche pour le point laser, et c'est la seule pièce qui ne serre rien ; à 7 mm d'épaisseur, elle est sous la taille minimale du FDM |
| `support_laser_<modèle>.stl` | SLS, nylon 3201PA-F | gris-noir | le bec de l'encoche travaille en tension et prend des chocs : pas de résine |

- **Pas de PLA** : sa tenue en température est de 65 °C, il se déforme dans une voiture au
  soleil.
- **Résine SLA** : commandable, précise (± 0,2 mm) et la moins chère, mais JLC3DP la
  déconseille lui-même en extérieur, à la chaleur et au soleil. Ses résines tiennent 56 à
  59 °C et cassent à 5 à 10 % d'allongement, contre 35 % pour le nylon 3201PA-F. À réserver
  à la cible (résine 9000HE, blanche, la plus tenace des résines bon marché), où rien
  n'est serré : la vis de charnière tourne librement dans la lumière du charnon. À éviter
  pour le coulisseau, où des vis sont serrées sur des parois de 2 mm, et pour le socle, dont
  les crochets reprennent toute la traction.
- **Tolérance annoncée : ± 0,3 mm** dans toutes ces matières. Le jeu des roues en dépend :
  commander un seul jeu d'abord.
- Les cotes du modèle ont été pensées pour une imprimante à dépôt de fil ; en nylon fritté,
  les trous sortent plus près de la cote. Les vis passent dans des trous de passage : rien à
  régler de ce côté.

Prix lus dans le devis JLC3DP le 5 octobre 2026, pour le socle non évidé (114,31 cm³) :

| Procédé et matière | Prix du socle | Par cm³ |
|---|---|---|
| SLA, résine 9600 (blanc) | 10,40 $ | 0,09 $ |
| SLA, résine 9000HE (blanc, plus tenace) | 11,89 $ | 0,10 $ |
| SLA, résines 8228 ou LEDO 6060 | 14,86 $ | 0,13 $ |
| FDM, PLA | 15,47 $ | 0,14 $ |
| SLA, résine JLC Temp (101 °C) | 22,71 $ | 0,20 $ |
| SLS, nylon 3201PA-F | 28,23 $ | 0,25 $ |
| FDM, ABS | 34,79 $ | 0,30 $ |
| SLS, nylon 1172Pro (blanc) | 36,50 $ | 0,32 $ |
| MJF, nylon PA12 | 43,09 $ | 0,38 $ |
| FDM, ASA | 43,71 $ | 0,38 $ |

Le prix est proportionnel au volume (vérifié sur le coulisseau : 93,96 cm³, 8,55 $ en
résine 9600). Le port estimé pour quatre pièces était de 9,75 $. D'où, pour les fichiers
évidés (190 cm³), par calcul :

| Choix | Pièces | Port compris |
|---|---|---|
| Tout en nylon, cible en nylon blanc | ≈ 49 $ | ≈ 59 $ |
| **Tout en nylon, cible en résine 9000HE (choix retenu)** | **≈ 44 $** | **≈ 54 $** |
| Coulisseau et petites pièces en nylon, socle et cible en résine 9000HE | ≈ 29 $ | ≈ 39 $ |
| Tout en résine 9000HE | ≈ 20 $ | ≈ 30 $ |

La résine coûte 2,5 fois moins que le nylon, mais elle casse plus facilement, tient 56 à
60 °C et vieillit au soleil. Le coulisseau est la pièce qui en souffrirait le plus : il
porte les roues, leurs écrous frein et les oreilles de charnière, où la vis est serrée sur
2 mm de matière. Le socle vient ensuite : ses crochets reprennent toute la traction. Le
mettre en résine économise ≈ 15 $ ; c'était le choix affiché jusqu'au 8 octobre 2026.

Pour obtenir le devis :

1. Créer un compte sur [jlc3dp.com/3d-printing-quote](https://jlc3dp.com/3d-printing-quote)
   (c'est le compte JLCPCB).
2. Déposer les 7 fichiers du banc et le support de votre télémètre (formats acceptés : STL, STEP, OBJ, 3MF), en millimètres.
3. Pour chaque fichier, choisir le procédé, la matière, la couleur et la quantité.
4. Le prix s'affiche aussitôt, pièce par pièce ; changer de matière le met à jour.
5. Ajouter au panier, choisir la livraison (c'est elle qui pèse le plus sur une petite
   commande) et payer.

Je n'ai pas pu lire le prix : le devis demande un compte.

### Quelle vis où : lisse ou filetée

| Emplacement | Ce qui bouge dessus | Ce qu'il faut |
|---|---|---|
| Charnière de la cible | la cible tourne et coulisse sur le bout de la vis | vis M3×12 à tête bombée et écrou frein M3 ; elle est filetée d'un bout à l'autre, la cible porte donc sur le filet |
| Axe de poulie | le roulement tourne autour, entre ses entretoises | vis CHC M5×40 et écrou frein M5 ; à filetage partiel (≈ 18 mm de tige lisse), le roulement porte sur la tige lisse |
| Bobines des élévateurs | rien : la vis est enfermée dans les bobines | vis CHC M5×80, filetée au bout pour l'écrou |
| Roues | rien : la bague du roulement est serrée, elle ne tourne pas sur la vis | vis M5×25 tête bombée, forcément filetée sur toute sa longueur, et écrou frein |

## Fabriquer par lots de 10

Prix relevés en ligne ou estimés, à revérifier au moment de commander. Le télémètre et le
lest ne sont pas comptés : chacun utilise le sien.

| Pièce | Par lot de 10 | Où | Prix du lot |
|---|---|---|---|
| Roues V Ø24 × 10,23, roulements 625 | 40 | AliExpress, 4 lots de 10 ; en France : 3delectroshop.fr | 20–50 € (≈ 90 € en France) |
| Vis M5×25 tête bombée (ISO 7380) | 40 | marleva.net | ≈ 5 € |
| Roulements 625ZZ (poulies) | 10 | AliExpress (≈ 3 $ les 10), reprap-france.com (1,10 € pièce) ; ou les roues en trop | 0–11 € |
| Vis CHC M5×40 (poulies) | 10 | visseriefixations.fr | ≈ 1,30 € |
| Vis CHC M5×80 | 10 | marleva.net, planetaventure.com (2,58 € le sachet de 10) | 3–9 € |
| Écrous frein M5 | 60 | marleva.net | ≈ 4 € |
| Vis M3×12 tête bombée et écrous frein M3 (charnières) | 20 + 20 | visseriefixations.fr | ≈ 2 € |
| Cordelette de 2 mm | 15 m | bobine de drisse ou de paracorde 2 mm, magasin de sport ou AliExpress | 6–12 € |
| Sangle velcro 20 mm | 10 | magasin de bricolage | ≈ 8 € |
| **Quincaillerie pour 10 bancs** | | | **≈ 60–100 €** |

### Où faire imprimer 80 pièces (≈ 1,3 kg de PETG par lot)

- **Votre propre imprimante** : c'est le bon choix à ce volume. Le filament revient à
  ≈ 30 € par lot (≈ 2,5 centimes le gramme en Europe), soit 3 € par banc ;
  compter une dizaine d'heures d'impression par banc. Les plus grandes pièces mesurent
  164 × 80 mm (socle) et 130 × 85 mm (coulisseau) : un plateau de 180 mm suffit. Une imprimante d'entrée de gamme est amortie dès
  le deuxième ou le troisième lot par rapport à un service.
- **JLC3DP** (Chine) : devis instantané en déposant les 8 STL (banc + support) en quantité 10. Les services
  d'impression à dépôt de fil facturent typiquement 0,05 à 0,15 $ le gramme plus des frais
  par pièce ; à ce tarif, compter 100 à 250 € par lot, port et TVA compris, et deux à trois
  semaines. À confirmer par le devis.
- **Un fablab ou un particulier équipé près de chez vous** : à négocier au lot ; c'est
  souvent moins cher qu'un service en ligne et sans délai de transport.
- **Craftcloud** : pour comparer en un envoi plusieurs imprimeurs, dont des européens.

Coût de revient indicatif par banc : **≈ 10–15 €** en imprimant soi-même, **≈ 16–35 €** en
passant par un service.

## Montage

Schéma d'ensemble avec toute la visserie : [schema_montage.png](apercu/schema_montage.png).
Détails : [A roue](apercu/schema_A_roue.png), [B poulie](apercu/schema_B_poulie.png),
[C bobines des élévateurs](apercu/schema_C_axe_elevateurs.png), [D charnière](apercu/schema_D_charniere.png),
[E cordelette](apercu/schema_E_cordelette.png), [F verrouillage de la cible](apercu/schema_F_verrou_cible.png).

1. **Poulie** : chasser un roulement 625 d'une roue en trop et l'emmancher dans la poulie,
   jusqu'à la lèvre. Poser la poulie dans sa fente, par le dessus du socle, une entretoise
   imprimée de chaque côté du roulement. Glisser un écrou frein M5 dans son logement, sur un
   flanc du socle, bague nylon vers l'extérieur. Par l'autre flanc, passer la vis M5 × 40 à
   travers le crochet, une entretoise, le roulement, l'autre entretoise et l'autre crochet,
   et la visser à la clé Allen de 4 jusqu'à ce que sa tête porte au fond de son logement.
   Inutile de serrer fort : c'est l'écrou frein qui la retient. Tête et écrou restent sous
   les flancs. La poulie doit tourner sans aucun point dur.
2. **Roues** : glisser un écrou frein M5 dans chacun des 4 logements du dessus du coulisseau,
   bague nylon vers le haut, puis poser le coulisseau sur le socle. Pour chaque roue, une vis
   M5×25 monte par le dessous (tête sous la roue), traverse la roue présentée dans la rainure
   puis une entretoise imprimée, et se visse dans l'écrou frein, que son logement empêche de
   tourner. Ni colle ni frein-filet.
3. **Réglage du jeu** : un côté du coulisseau a des trous oblongs. Serrer d'abord le côté
   fixe, pousser les deux autres roues au fond de leur rainure, serrer. Le coulisseau doit
   rouler seul d'une butée à l'autre quand on incline le socle, sans jeu ni point dur : c'est
   ce réglage qui fait la qualité du roulement. Trop serré, il freine ; trop lâche, le
   coulisseau se met de travers.
4. **Bobines des élévateurs** : enfiler sur la vis M5×80 la bobine à logement rond (chapeau
   côté tête), traverser la nervure centrale, puis l'autre bobine (chapeau vers l'extérieur).
   Glisser l'écrou frein dans son logement hexagonal et serrer à la clé Allen : les bobines
   sont pincées contre la nervure, tête et écrou disparaissent dans les chapeaux. Ce montage
   est définitif, on n'y touche plus.
5. **Cible** : glisser un écrou frein M3 dans le logement de chaque oreille, sur sa face
   intérieure, bague nylon vers la cible. Présenter la cible entre les oreilles : ses
   charnons retiennent les écrous. De chaque côté, visser une vis M3 × 12 à travers
   l'oreille, à la clé Allen de 2, jusqu'à ce que sa tête porte : elle est alors bloquée sur
   l'oreille, et son bout, entré dans la lumière du charnon, sert d'axe. La cible doit
   tourner et monter de 5,5 mm librement.
6. **Cordelette** : relever la cible. Le puits du nœud est juste derrière elle, sur le
   dessus du coulisseau. Y enfiler la cordelette, la faire sortir par la fente du fond, faire
   un nœud en huit dans le puits (il ne passe pas par la fente). Le brin court dans le canal
   du socle, passe sur la poulie et se noue à la poignée du lest.
7. **Lest** : peser le lest rempli à **5,00 kg** sur une balance de cuisine.

## Utilisation

1. Poser le socle sur la table, crochets contre le chant. Relever la cible : la soulever, la
   redresser, puis la pousser vers le bas jusqu'à ce qu'elle se coince. Elle est alors
   verrouillée d'équerre. Voir [le verrouillage](apercu/schema_F_verrou_cible.png).
2. Régler la longueur de cordelette pour que **la poche repose au sol quand la suspente est
   relâchée**, et décolle dès qu'on tire. Le socle n'est stable que lorsque la suspente tire
   dessus : poche suspendue et suspente molle, il bascule dans le vide. En cas de doute, une
   pince sur le dessus d'une joue le sécurise.
3. Poser les deux élévateurs à plat, un de chaque côté de la nervure. Passer la boucle de
   base de chacun par-dessus le chapeau de sa bobine, sans rien dévisser, puis coucher la
   sangle dans son couloir. Pour l'enlever : détendre, sortir la sangle du couloir, repasser
   la boucle par-dessus le chapeau. Voir [l'accrochage](apercu/accrochage_elevateurs.png),
   [la vue de dessus](apercu/accrochage_dessus.png) et [le profil](apercu/accrochage_profil.png).
4. Côté voile, glisser la suspente dans l'encoche du support du laser, par en dessous, et
   tirer jusqu'à ce que la patte bute contre le bec. Reculer jusqu'à ce que
   la poche décolle et que le coulisseau quitte sa butée (100 mm de course), sans aller
   jusqu'à la butée avant.
5. Viser toujours le trait horizontal de la mire : à hauteur constante, un éventuel défaut
   d'équerrage de la cible ne change rien à la mesure. Déclencher, noter `lecture + K`. Trois
   lectures par suspente.

### Étalonnage de K

La longueur mesurée va de la boucle de base de l'élévateur à la patte d'attache : elle
comprend l'élévateur. Tendre une suspente sur le banc, la mesurer au mètre ruban acier de
la bobine à la patte, lire le laser au même moment : `K = ruban − laser`. Refaire sur trois
suspentes, garder la moyenne.

### Transport

Rabattre la cible, enrouler la cordelette, passer une sangle velcro autour du bloc entre les
deux paires de roues : elle tient la cible fermée et empêche le coulisseau de rouler.

## Choix faits pour rester plat

- **Accrochage des élévateurs à l'horizontale**, dans l'épaisseur du bloc : les chapeaux des
  bobines et les joues des couloirs ne dépassent pas des oreilles de charnière.
- **Pas d'entretoises excentriques.** Elles ajoutaient 5 mm ; le jeu se règle par les trous
  oblongs.
- **Petite poulie** Ø25 sur roulement, logée dans le bloc des crochets, sous le passage du
  coulisseau : elle n'ajoute rien à l'épaisseur ni à la longueur.

## Améliorations possibles

Par ordre d'intérêt ; aucune n'est faite.

1. **Tenir le socle sur la table.** C'est le point faible : poche suspendue et suspente
   relâchée, il bascule. Une mâchoire réglable sous la table (une vis à oreilles dans le
   crochet) le rendrait sûr, pour une vis de plus.
2. **Verrou de transport imprimé.** Un loquet qui tient la cible rabattue et bloque le
   coulisseau éviterait la sangle velcro.
3. **Repère de mi-course.** Une languette de couleur vive sur le coulisseau, visible de loin,
   pour savoir sans revenir au banc qu'il flotte entre ses butées.
4. **Cale d'étalonnage.** Une tige de longueur connue qui se monte entre la bobine et le
   support du laser : elle donne la constante K en une mesure, sans mètre ruban.
5. **Cible mate.** Un autocollant blanc mat ou un papier collé : le point laser se lit mieux
   que sur du PETG brillant.
6. **Saisie des mesures.** Avec un télémètre Bluetooth, un tableau qui compare directement
   chaque suspente à la valeur constructeur et à sa symétrique.

## Points à vérifier sur la première impression

- **Profil des roues.** Les rainures sont dessinées pour une roue Ø23,9 × 10,23 mm avec un
  méplat de 5,9 mm (cote OpenBuilds). Les trous oblongs rattrapent ±1 mm. Au-delà, ajuster
  `wheel_od`, `wheel_w` et `wheel_flat` dans `banc.scad`.
- **Garde au-dessus du socle** : le coulisseau passe à 1 mm du socle avec les entretoises
  de 2,7 mm. S'il frotte, les réimprimer un peu plus hautes (`spacer_h`), de 0,5 mm au plus :
  au-delà, la vis des roues n'atteint plus la bague nylon de l'écrou frein.
- **Largeur des roues sur leurs roulements** : le modèle compte 11 mm (deux roulements de
  5 mm et leur cale de 1 mm, qui dépassent la roue de 0,4 mm par face). La mesurer sur vos
  roues ; si elle diffère, corriger `wheel_stack`.
- **Vis de la poulie et des charnières** : elles passent dans des trous de passage (Ø 5,3
  et Ø 3,3) et sont arrêtées par des écrous frein ; il n'y a rien à ajuster. Si un écrou
  n'entre pas dans son logement, l'ébavurer au cutter. Serrer jusqu'au contact, sans
  écraser le plastique.
- **Logement du roulement** (Ø16,15) dans la poulie : selon l'imprimante, il peut falloir
  ±0,1 mm. Le roulement doit tenir sans jeu.
- **Canal de la cordelette** : la fente de 3 mm au fond du puits doit laisser passer la
  cordelette mais pas le nœud ; vérifier que le brin ne frotte nulle part sur la longueur du
  canal quand le coulisseau avance.
- **Table** : le crochet descend de 14 mm ; il faut un chant franc, peu arrondi.
- **Élévateurs** : bobines et couloirs sont réglés sur vos sangles de 25 mm de large et 5 mm
  d'épaisseur (`elev_w = 26`, `elev_t = 5`). Vérifier que leur boucle de base passe
  par-dessus un chapeau de 14 mm.
- **Épaisseur de la sangle** : il y a 5,7 mm entre la bobine et le plancher, pour une boucle
  de 5 mm (0,7 mm de jeu). L'axe des bobines a été relevé de 3 mm pour cela, ce qui épaissit le
  banc plié d'autant ; pour une autre épaisseur, changer `pin_z` (1 mm de sangle par
  millimètre). Le chapeau ne dépasse la bobine que de 2,5 mm : c'est surtout la joue du
  couloir qui empêche une sangle aussi épaisse de glisser de côté. Le plancher est échancré
  sous les chapeaux pour laisser passer la boucle quand on l'enfile.
- **Support du laser** : vérifier que le télémètre entre dans l'auge sans forcer (`fit`), que
  ses boutons latéraux tombent dans le dégagement, et que vos suspentes les plus grosses
  passent dans l'encoche (`slit_w`) sans que la patte ne passe. Si la première couche a
  refermé l'encoche, la rouvrir d'un coup de lame.
- **Verrouillage de la cible** : la languette (3 mm) doit se coincer dans la lèvre en
  poussant à la main, et se libérer en soulevant. Si c'est trop dur ou trop lâche sur votre
  imprimante, décaler la lèvre de ±0,1 mm (premier point de `lip` dans `coulisseau()`).

## Le dépôt et le site

Ce dossier est le dépôt public <https://github.com/alexandre-pereira/trimming-tools> :
`scad/` (modèles), `stl/` (fichiers à imprimer), `apercu/` (images et schémas), `outils/`
(scripts qui produisent les STL, les images et le site). Le site est publié sur
<https://trimming-tools.wesoar.fr> (et <https://alexandre-pereira.github.io/trimming-tools/>).

Le site de présentation est construit à partir du README par `outils/site.py` : il
reprend ses sections, les images et propose les STL au téléchargement. GitHub Actions le
reconstruit et le publie à chaque changement sur la branche `main`
(`.github/workflows/pages.yml`), si bien que le site suit le dossier. Pour le voir en local :

```
pip install markdown
python outils/site.py
```

puis ouvrir `_site/index.html`.

Le site existe en deux langues : en anglais à sa racine (la langue par défaut), depuis
`README.en.md`, et en français dans `fr/`, depuis `README.md`. **Ce qui change dans un README
se reporte dans l'autre**, sinon les deux pages ne disent plus la même chose ; seul le
tableau des supports du laser est écrit dans les deux par `outils/generer_stl.mjs`. Un
visiteur dont le navigateur est en français arrive sur la page française, et le choix fait
avec le sélecteur EN / FR est retenu.

L'habillage (`outils/wesoar.css`, `wesoar.svg`, `wesoar-mark.svg` : feuille de style,
logo, icône de l'onglet) est celui de tous les outils WeSoar ; les mêmes fichiers sont dans
le dépôt de PG Soundings (`scripts/`). Une modification s'y reporte telle quelle ; ce qui
est propre à cette page reste dans `site.py`.

## Ce qui a été vérifié, et ce qui ne l'a pas été

Vérifié sur le modèle : maillages fermés ; aucune interférence entre socle, coulisseau,
poulie, roues, bobines des élévateurs et cible, cible relevée comme rabattue, coulisseau aux
deux bouts de course et à mi-course. Rien n'a été imprimé ni essayé en charge ; le réglage
du jeu des roues et le passage de la cordelette dans le canal sont à valider sur la première
impression. Les tensions annoncées plus haut sont calculées, pas mesurées.

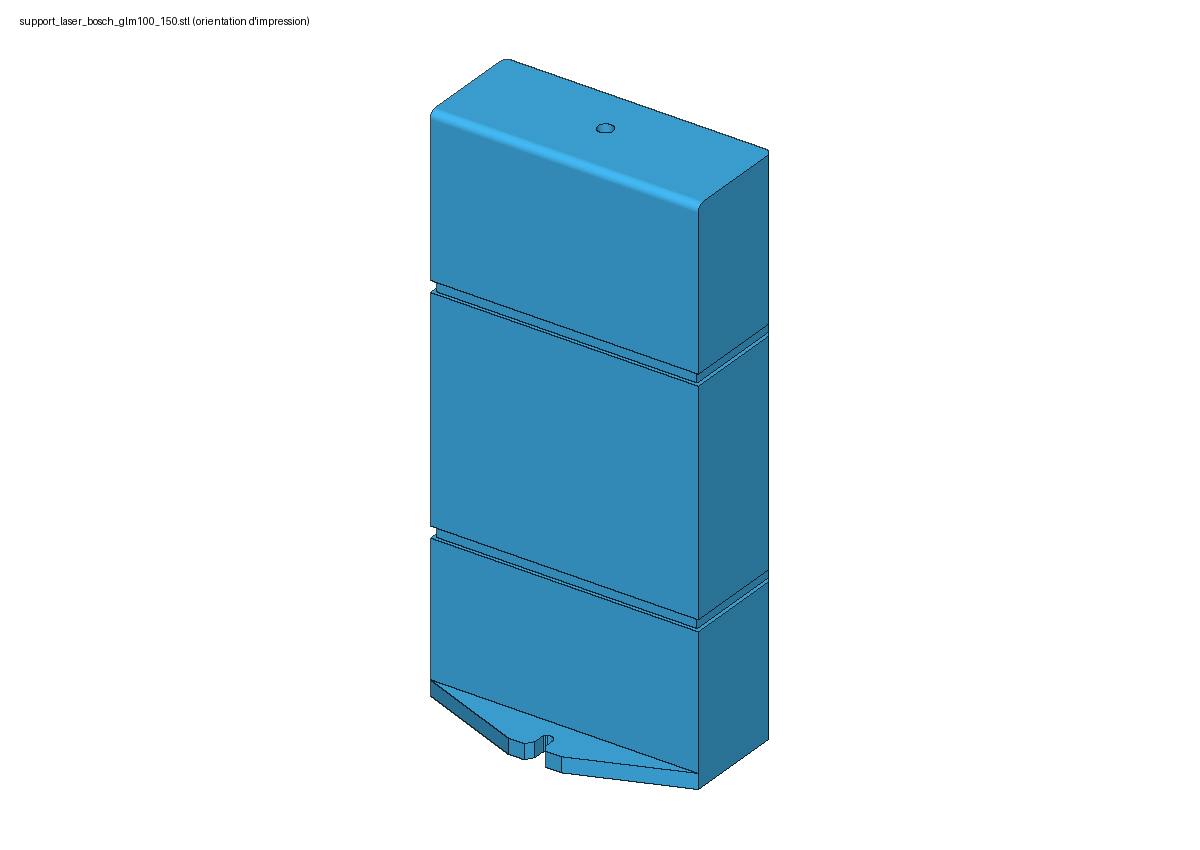
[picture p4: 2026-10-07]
apercu/support_laser_bosch_glm100_150.png

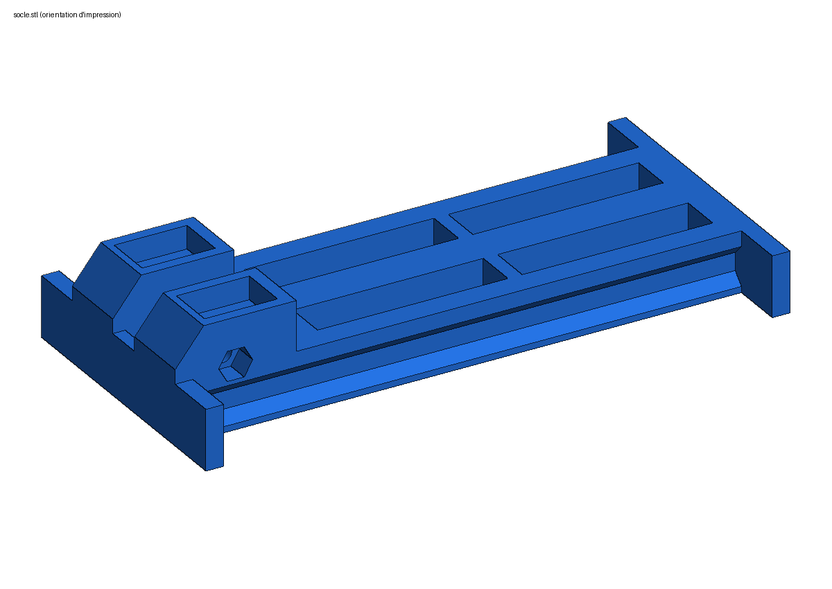
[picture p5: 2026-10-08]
apercu/socle.png

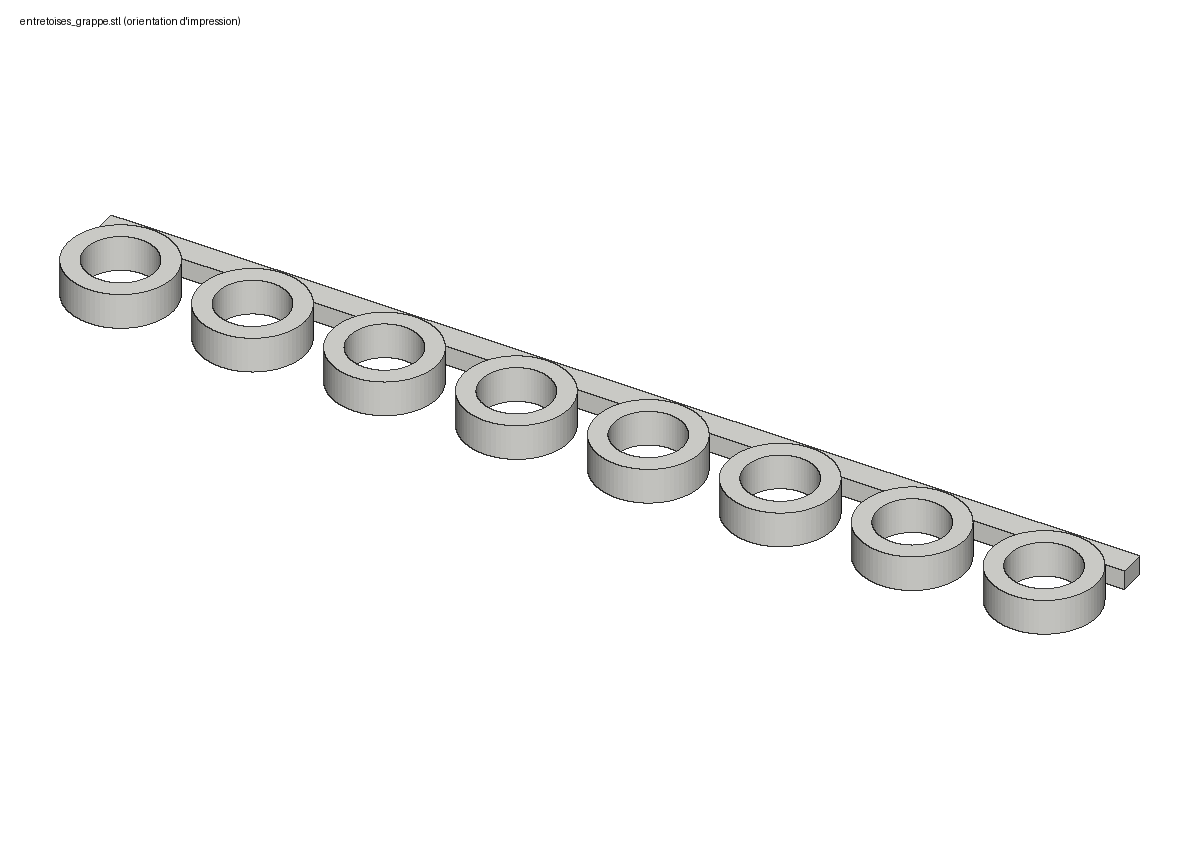
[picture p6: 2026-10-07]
apercu/entretoises_grappe.png

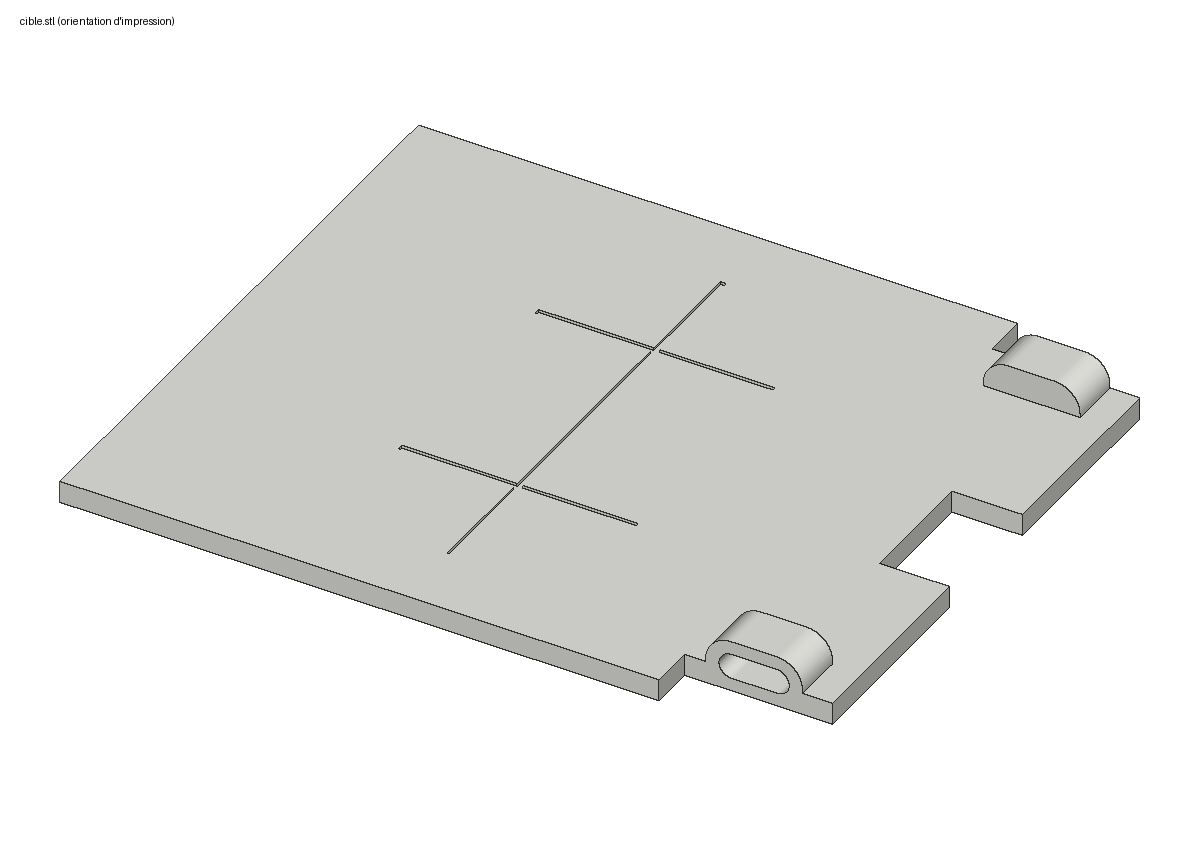
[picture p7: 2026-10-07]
apercu/cible.png

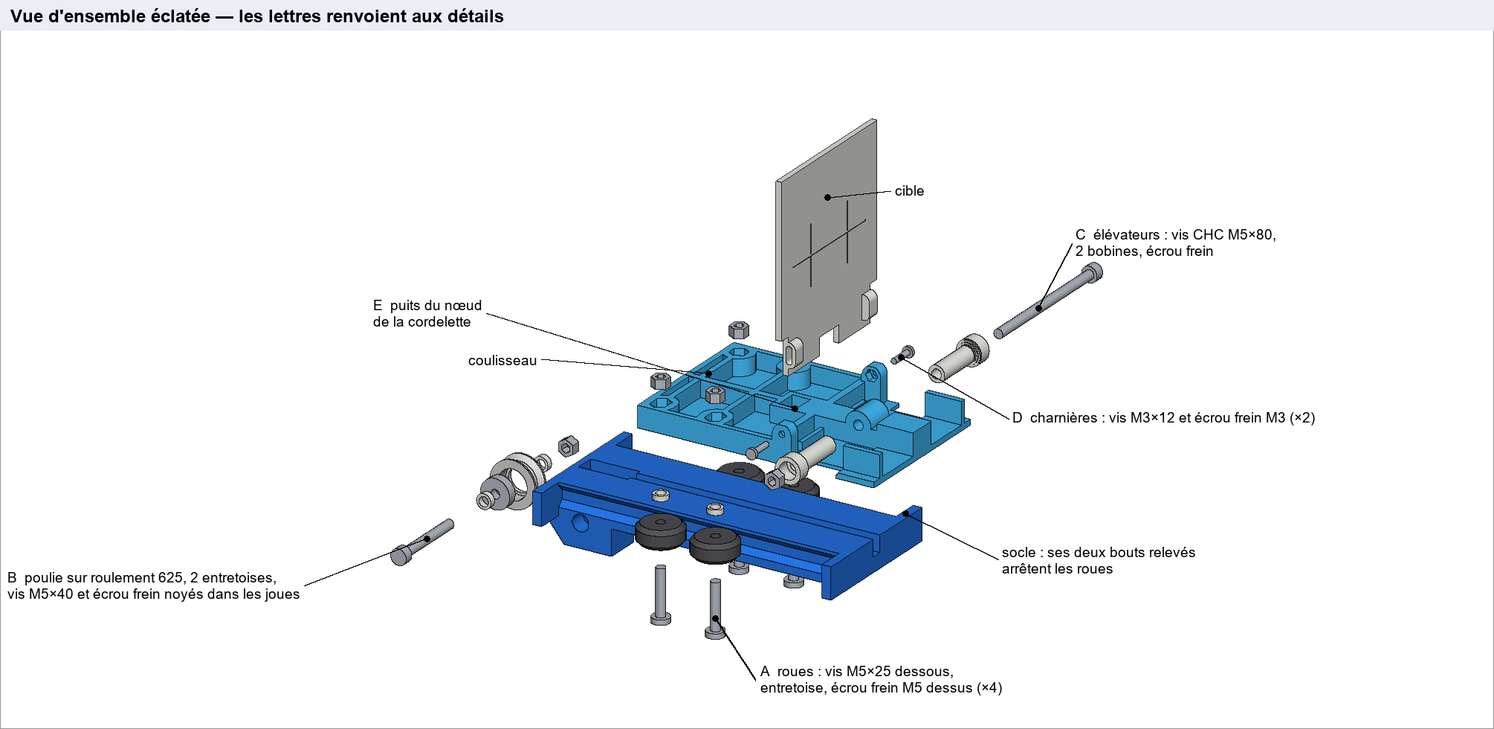
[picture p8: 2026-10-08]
apercu/schema_ensemble.png

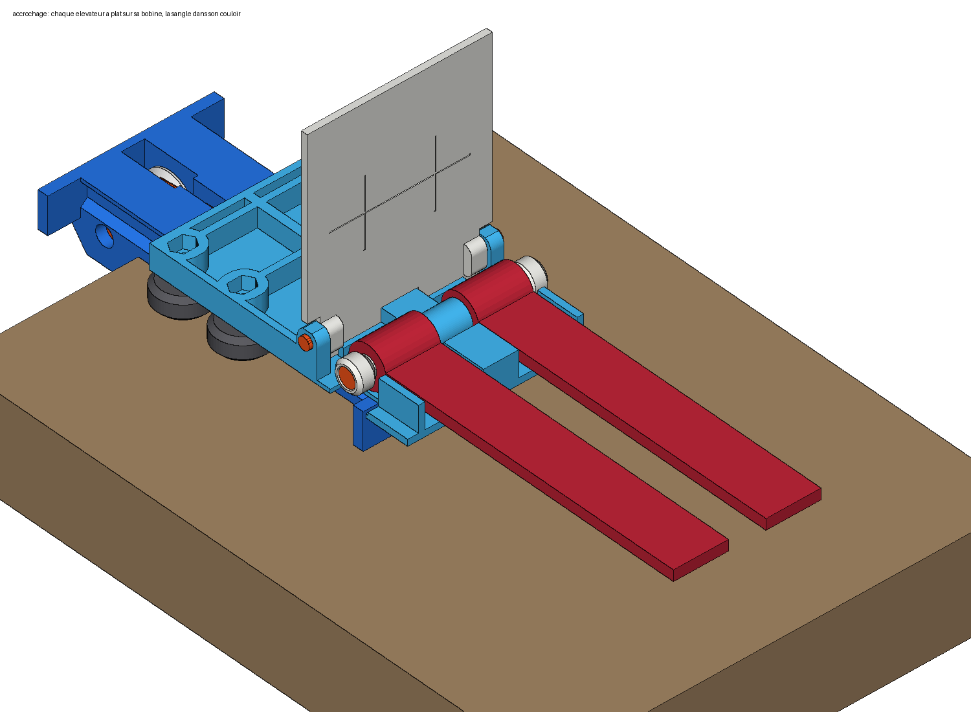
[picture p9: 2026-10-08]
apercu/accrochage_elevateurs.png

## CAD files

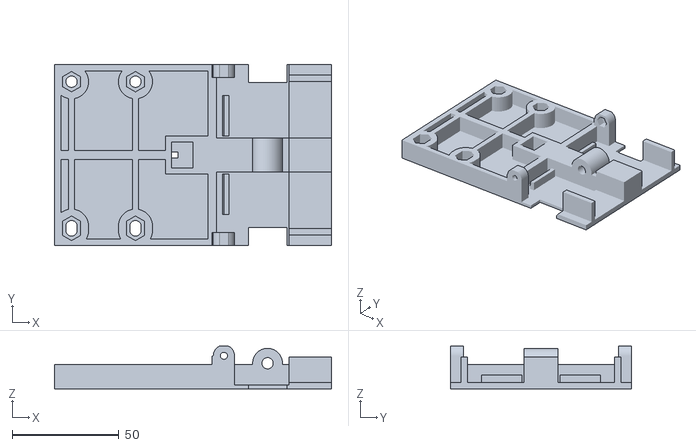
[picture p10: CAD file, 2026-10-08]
stl/coulisseau.stl
130.0 x 84.8 x 20.0

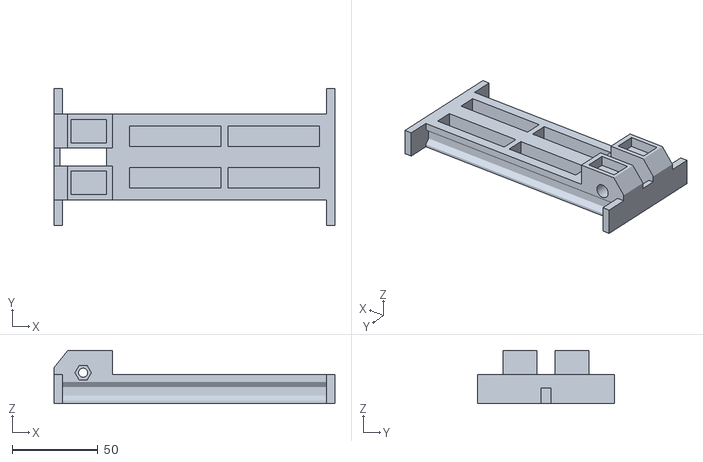
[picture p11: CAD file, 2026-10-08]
stl/socle.stl
163.9 x 80.0 x 31.0

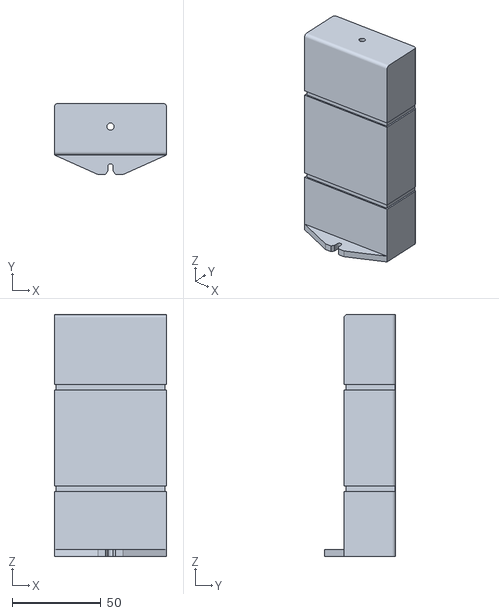
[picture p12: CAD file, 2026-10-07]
stl/support_laser_leica_x3_x4.stl
63.0 x 40.0 x 136.0

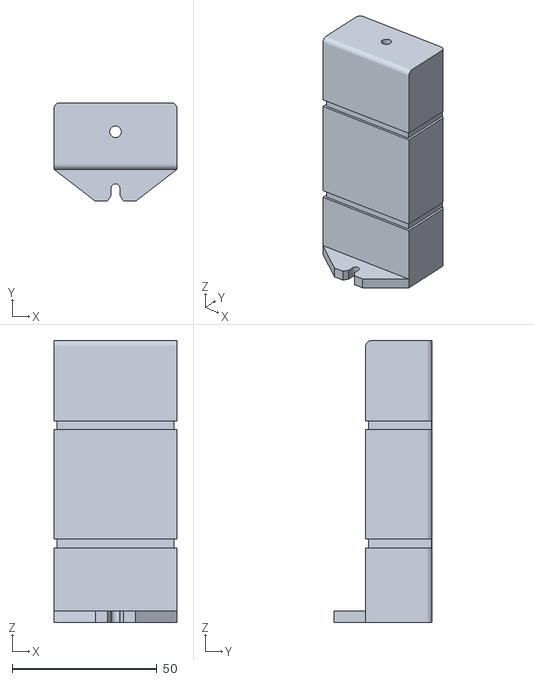
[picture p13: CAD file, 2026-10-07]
stl/support_laser_bosch_plm30.stl
42.5 x 34.0 x 97.5

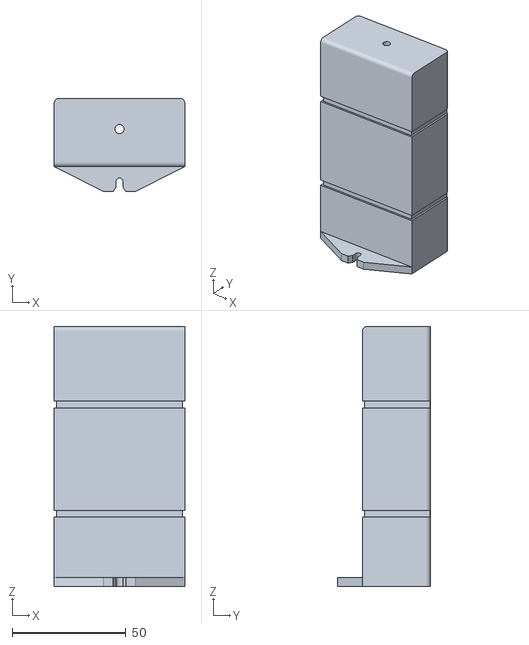
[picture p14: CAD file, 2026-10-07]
stl/support_laser_bosch_glm80.stl
57.5 x 41.0 x 114.5

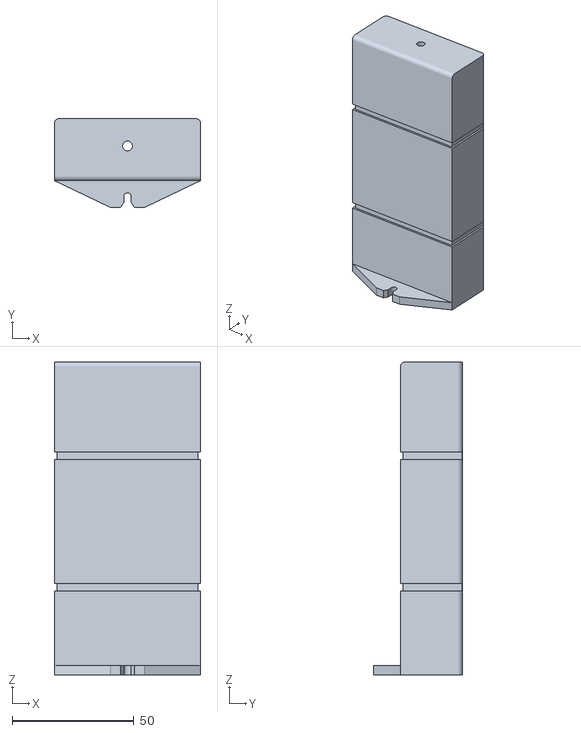
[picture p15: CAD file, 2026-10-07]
stl/support_laser_leica_x1.stl
60.0 x 36.5 x 128.5

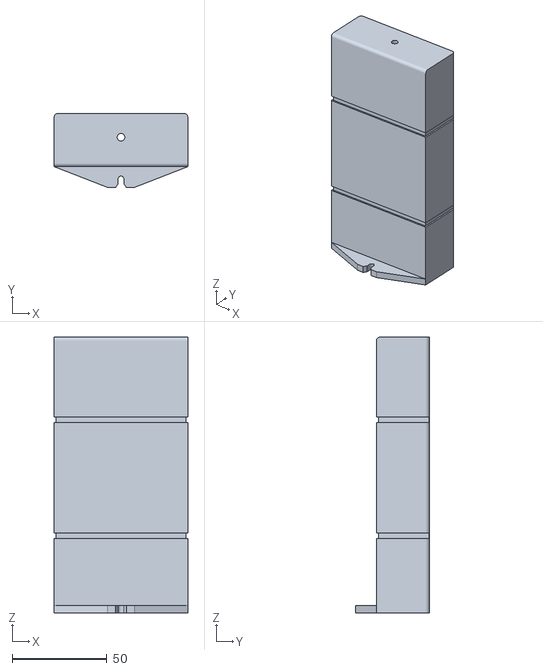
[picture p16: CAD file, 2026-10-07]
stl/support_laser_bosch_glm100_150.stl
70.5 x 39.0 x 145.5

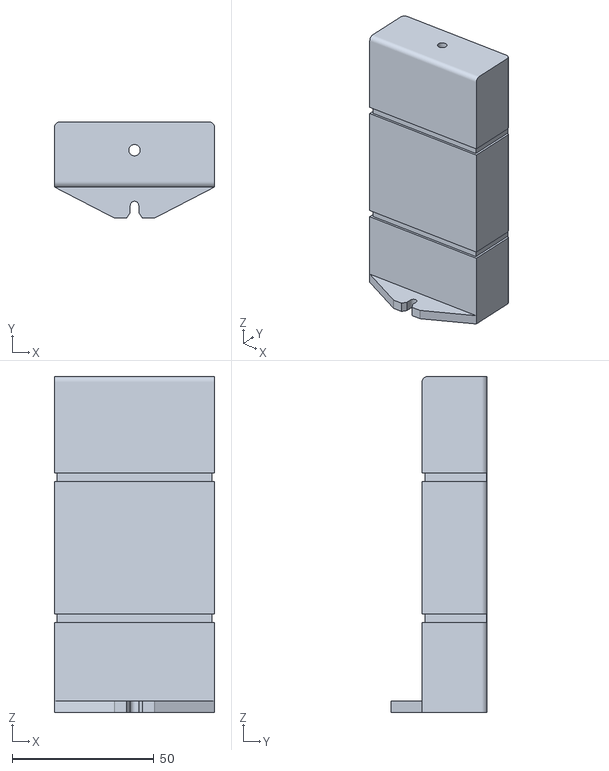
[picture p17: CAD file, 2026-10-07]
stl/support_laser_bosch_plm70_27.stl
56.5 x 34.0 x 118.5

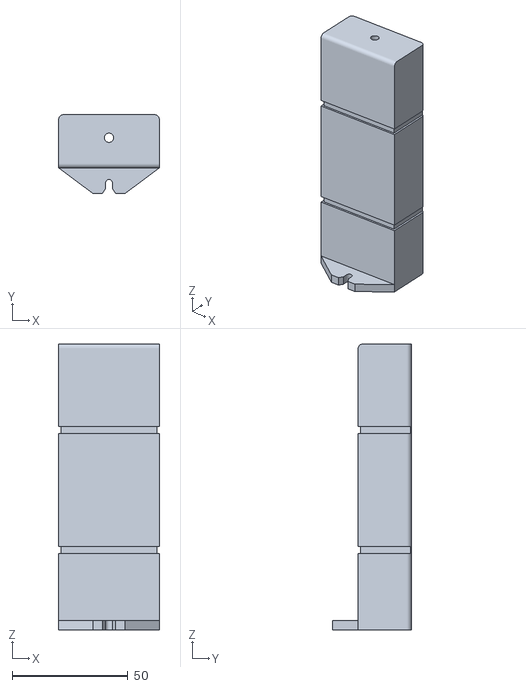
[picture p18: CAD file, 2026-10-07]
stl/support_laser_leica_d110.stl
43.5 x 34.0 x 123.5

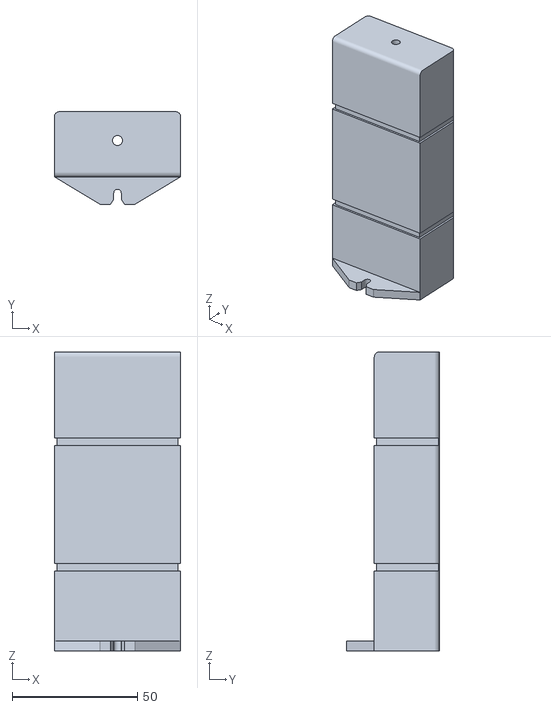
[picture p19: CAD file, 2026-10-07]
stl/support_laser_leica_d2_v1.stl
50.5 x 37.0 x 119.5

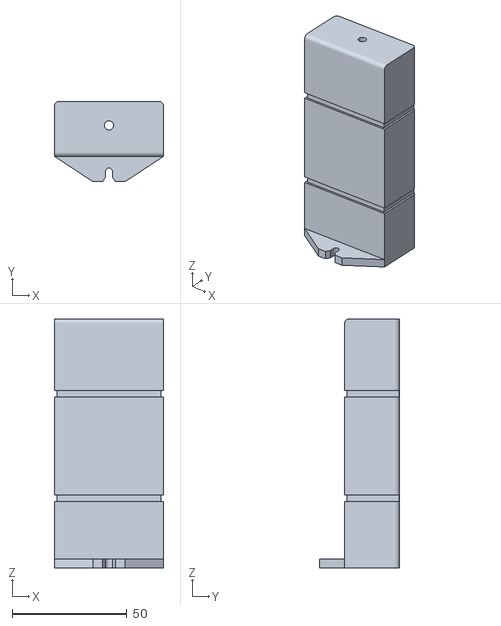
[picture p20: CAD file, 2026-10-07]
stl/support_laser_bosch_glm40.stl
47.5 x 35.0 x 108.5

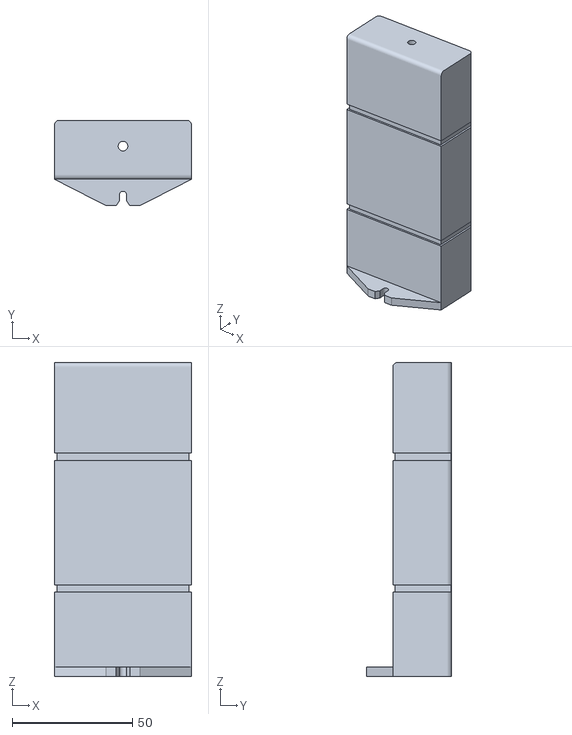
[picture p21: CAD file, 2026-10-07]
stl/support_laser_leica_d2_2025.stl
57.0 x 35.5 x 130.5

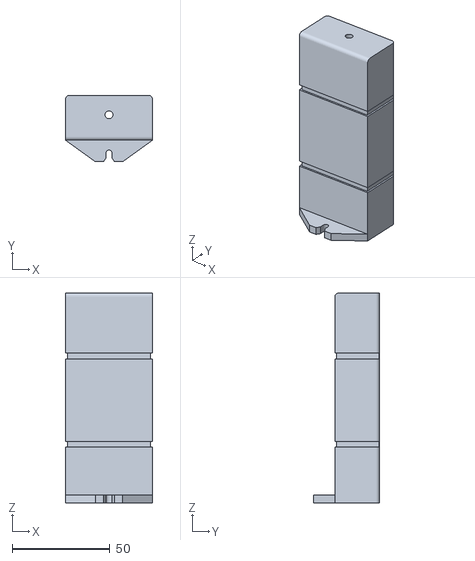
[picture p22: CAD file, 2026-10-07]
stl/support_laser_bosch_zamo.stl
44.5 x 34.0 x 107.5

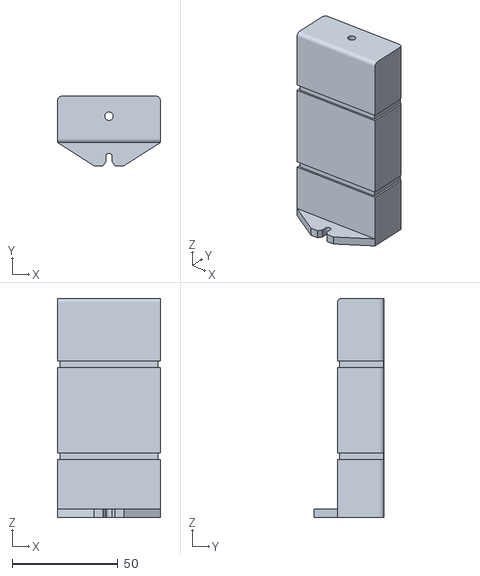
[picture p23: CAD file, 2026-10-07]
stl/support_laser_bosch_plm40_70.stl
48.5 x 33.0 x 103.5

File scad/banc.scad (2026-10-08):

// ============================================================
//  Banc de calage parapente compact et plat, à poser sur un chant de table
//  (même principe que l'EasyTrim) — laser + poche à eau de 5 kg.
//
//  Un socle s'accroche au bord de la table et porte la poulie de renvoi, logée dans le bloc
//  des crochets, sous le passage du coulisseau ; la cordelette rejoint le coulisseau par un canal
//  creusé dans le dessus du socle. Un coulisseau roule dessus sur 4 roues en V montées sur vis M5 ; il porte
//  à l'avant un plot central et deux bobines où s'accrochent les deux élévateurs posés à plat
//  et, juste derrière, la cible articulée ; à l'arrière, la cordelette de la poche à eau.
//  La cible se rabat vers l'arrière, à plat sur le coulisseau, pour le transport.
//
//  Repère : x = axe de traction, +x vers la voile ; chant de la table en x = 0 ;
//  dessus de la table en z = 0. La poche à eau pend en x < 0.
// ============================================================

part = "assemblage";   // socle | coulisseau | poulie | cible | bobine_tete | bobine_ecrou | entretoises_grappe | assemblage
plie = false;          // assemblage : true = cible rabattue, coulisseau en butée arrière (transport)
alleg = true;          // socle et coulisseau évidés : un cinquième de matière en moins, donc moins cher chez un imprimeur

// --- Socle ---
T        = 17;     // épaisseur
wheel_z  = 9.8;    // plan de roulement des roues (1,5 mm entre les têtes de vis et la table)
base_w   = 50;     // largeur entre les deux rainures en V
travel   = 100;    // course du coulisseau (chaque mm de course allonge le socle d'autant)
stop_t   = 5;      // épaisseur des butées de fin de course
stop_w   = 80;     // largeur des butées
lug_drop = 14;     // hauteur du crochet sous le dessus de la table (il dépasse la poulie pour la protéger)
lug_len  = 34;     // avancée des joues devant le chant ; le socle (et ses rainures) commence au bout des joues
chan_w   = 6;      // canal de la cordelette dans le dessus du socle, sous le coulisseau

// --- Roues V Ø24 pour profilé V-slot (2 roulements 625) ---
wheel_od   = 23.9;
wheel_w    = 10.23;
wheel_stack = 11;    // largeur sur les deux roulements 625 et leur cale de 1 mm : ils dépassent la roue de 0,4 mm par face.
                     // C'est cette cote, et non wheel_w, qui compte le long de la vis.
wheel_flat = 5.9;    // largeur du méplat de la bande de roulement
wheel_px   = 30;     // entraxe longitudinal des roues. Chaque mm d'entraxe en moins raccourcit le socle d'autant
                     // (ou rend 1 mm de course) ; en dessous de 28 mm les roues se toucheraient.
spacer_h   = 2.7;    // entretoise imprimée entre la roue et le coulisseau.
                     // Vis M5×25 : 11 (roue) + 2,7 (entretoise) + 5,3 (matière sous l'écrou) = 19 ; l'écrou frein (5 mm)
                     // va de 19 à 24, la vis le dépasse de 1 mm (bague nylon en prise) et reste sous le dessus du coulisseau.
n_spacer   = 8;      // entretoises dans la grappe (4 pour les roues, 2 pour la poulie, 2 de rechange)
groove_flat  = 5.0;  // fond de la rainure du socle, plus étroit que le méplat :
groove_depth = 3.0;  // la roue porte sur ses chanfreins, pas sur le fond

// --- Coulisseau ---
sl_t     = 11.5;   // épaisseur : elle loge un écrou frein M5 (5 mm) au bout de la vis M5×25 des roues
sl_rear  = 28;     // débord arrière (côté poulie) depuis le milieu des roues
sl_front = 48;     // débord avant (côté voile)
pit_x    = 27;     // puits du nœud de la cordelette : le plus en avant possible, pour que le brin reste presque horizontal
edge     = 8;      // matière entre l'axe d'une roue et le bord
nut_h    = 6.2;    // logement des écrous frein M5 des roues : écrou noyé, 5,3 mm de matière dessous (voir spacer_h)
adj      = 1;      // côté -y : trous oblongs de ±1 mm pour régler le jeu des roues

// --- Accrochage des 2 élévateurs : nervure centrale traversée par une vis M5, une bobine de chaque côté ---
// Les élévateurs sont posés à plat. Leur boucle de base se passe par-dessus le chapeau de la bobine,
// sans rien dévisser ; la sangle se couche ensuite dans son couloir, entre la nervure centrale et une joue.
// La vis est montée une fois pour toutes ; sa tête et son écrou sont noyés dans les chapeaux :
// la sangle ne touche que du plastique lisse, et aucune pièce ne se démonte à l'usage.
elev_w   = 26;     // longueur utile d'une bobine = largeur de la sangle de l'élévateur (25) + 1 mm
elev_t   = 5;      // épaisseur de la sangle à l'endroit de la boucle
post_w   = 16;     // largeur de la nervure centrale
pin_d    = 5.3;    // passage de la vis M5
pin_x    = 24;     // position de l'axe des bobines devant la face avant
pin_z    = 0.5;    // hauteur de l'axe au-dessus du dessus du coulisseau. Il reste sl_t + pin_z - bob_d/2 - floor_t
                   // (5,7 mm) entre la bobine et le plancher : la boucle de l'élévateur (elev_t = 5) y passe avec 0,7 mm de jeu.
                   // Chaque mm ajouté ici donne 1 mm de plus à la sangle et épaissit le banc plié d'autant.
boss_r   = 7;      // bossage de la nervure autour de l'axe
bob_d    = 9;      // diamètre des bobines, sur lesquelles porte la sangle
bob_fl   = 14;     // diamètre du chapeau
screw_l  = 80;     // vis CHC M5×80 (tête cylindrique à six pans creux)
pocket   = 6;      // logement de la tête (Ø8,5 × 5) dans un chapeau ; celui de l'écrou frein (5 mm) a 1 mm de plus,
                   // pour que la vis M5×80 dépasse l'écrou de 1,5 mm (bague nylon en prise) sans sortir du chapeau
cap_l    = (screw_l - 5.5 - 2*elev_w - post_w)/2 + pocket;   // longueur d'un chapeau (≈ 9,25)
cone_l   = (bob_fl - bob_d)/2;                               // raccord conique à 45° entre bobine et chapeau

// --- Plateau avant : plancher sous les bobines, puis deux couloirs qui tiennent les élévateurs à plat ---
tray_l   = 54;     // longueur du plateau devant la face avant
floor_t  = 1.8;    // plancher sous les bobines (la boucle passe entre la bobine et lui)
tray_t   = 3;      // fond des couloirs
ch_x0    = pin_x + bob_fl/2 + 3;   // début des couloirs, juste devant les chapeaux
fence_t  = 3;      // épaisseur des joues
fence_z  = 3.5;    // hauteur des joues au-dessus du dessus du coulisseau : elles montent jusqu'au dessus de la sangle tendue
fence_y  = post_w/2 + elev_w + 0.5;   // face intérieure des joues extérieures

// --- Poulie Ø25 sur un roulement 625ZZ, axe = vis CHC M5×40 et écrou frein, noyés dans les joues ---
// Elle est logée dans le bloc des crochets, sous le passage du coulisseau : rien ne dépasse du socle.
// Le roulement supprime le frottement de l'axe, qui fausserait la tension de la suspente.
pul_r    = 12.5;
pul_w    = 9.4;
slot_w   = 5 + 2*spacer_h + 0.2;   // fente de la poulie entre les joues (roulement 5 + une entretoise de chaque côté + jeu)
cord_d   = 2;      // cordelette 2 mm
axle_d   = 5.3;    // passage de la vis M5 dans les joues
axle_l   = 40;     // vis CHC M5×40 (DIN 912, tête Ø8,5 × 5) et écrou frein M5 (5 mm)
axle_hd  = 9.5;    // profondeur du logement de la tête (Ø9), côté -y : la tige lisse de la vis (18 mm) arrive ainsi
                   // jusque sous le roulement, et le bout fileté s'arrête 0,5 mm sous le flanc d'en face
axle_nd  = 6.5;    // profondeur du logement à six pans de l'écrou frein, côté +y : la vis le dépasse de 1 mm (bague nylon
                   // en prise). Tête et écrou restent sous les flancs, hors du passage des roues.
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

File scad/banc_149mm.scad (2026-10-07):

// ============================================================
//  Banc de calage parapente compact et court, à poser sur un chant de table
//  (même principe que l'EasyTrim) — laser + poche à eau de 5 kg.
//
//  Version « glissière inversée » : 100 mm de course pour 149 mm de long.
//  Les 4 roues en V sont fixées sur le socle, court, accroché au bord de la table.
//  Le coulisseau est un rail en U (la glissière) qui roule sur ces roues et peut
//  dépasser du socle des deux côtés, comme un tiroir. Il porte le plateau :
//  bobines des élévateurs, couloirs, cible articulée et verrouillée.
//  La version précédente (roues sur le coulisseau, 210 mm) est dans banc_210mm.scad.
//
//  Repère : x = axe de traction, +x vers la voile ; chant de la table en x = 0 ;
//  dessus de la table en z = 0. La poche à eau pend en x < 0.
// ============================================================

part = "assemblage";   // socle | glissiere | plateau | poulie | cible | petites_pieces | assemblage
plie = false;          // assemblage : true = cible rabattue, coulisseau rentré (transport)
xs_o = -999;           // assemblage : position imposée du coulisseau (sinon mi-course, ou rentré si plie)

// --- Socle ---
T        = 10;     // épaisseur ; le dessus est plat, il s'imprime retourné
base_w   = 50;     // largeur
travel   = 100;    // course du coulisseau
lug_drop = 12;     // hauteur du crochet sous le dessus de la table
lug_len  = 30;     // avancée des joues devant le chant (elles dépassent la poulie pour la protéger)
slot_w   = 11.8;   // fente de la poulie entre les joues (roulement 5 + une entretoise de chaque côté + jeu)

// --- Roues V Ø24 pour profilé V-slot (2 roulements 625), fixées debout sur le socle ---
wheel_od   = 23.9;
wheel_w    = 10.23;
wheel_flat = 5.9;    // largeur du méplat de la bande de roulement
wheel_px   = 32;     // entraxe longitudinal. Longueur du coulisseau = course + entraxe + 17 mm
wheel_x1   = 14;     // roues arrière, depuis le chant de la table
wheel_yb   = 18;     // demi-écartement des axes
adj        = 1;      // côté -y : trous oblongs de ±1 mm pour régler le jeu des roues
nut_p      = 4.2;    // logement des écrous M5 sous le socle
spacer_h   = 3.3;    // entretoises imprimées de la poulie
groove_flat  = 5.0;  // fond de la rainure des rails, plus étroit que le méplat :
groove_depth = 3.0;  // la roue porte sur ses chanfreins, pas sur le fond
chan_w   = 10;     // canal du socle où circule le taquet de butée de la glissière
chan_z   = 5;      // fond de ce canal

// --- Glissière : rail en U (âme + 2 rails) qui roule sur les roues ---
web_t    = 2.4;    // âme, sur laquelle se visse le plateau
rail_t   = 7;      // épaisseur des rails
rail_z0  = 3;      // bas des rails au-dessus de la table
end_t    = 3;      // cloison arrière : butée de fin de course côté voile
blk_w    = 8;      // taquet avant : attache de la cordelette et butée côté poche
blk_l    = 12;
acc_d    = 12;     // trous d'accès aux vis des roues, dans l'âme
xs_acc   = 34;     // position du coulisseau où ces trous sont au-dessus des roues

// --- Plateau (vissé sur la glissière) ---
sl_t     = 8;      // épaisseur
sl_w     = 84.8;   // largeur
sl_front = 48;     // face avant, dans le repère du coulisseau
fix_x    = [-35, 30];   // vis M3 fraisées qui tiennent le plateau sur les rails

// --- Accrochage des 2 élévateurs : nervure centrale traversée par une vis M5, une bobine de chaque côté ---
// Les élévateurs sont posés à plat. Leur boucle de base se passe par-dessus le chapeau de la bobine,
// sans rien dévisser ; la sangle se couche ensuite dans son couloir, entre la nervure centrale et une joue.
// La vis est montée une fois pour toutes ; sa tête et son écrou sont noyés dans les chapeaux :
// la sangle ne touche que du plastique lisse, et aucune pièce ne se démonte à l'usage.
elev_w   = 26;     // longueur utile d'une bobine = largeur de la sangle de l'élévateur + 1 mm
post_w   = 16;     // largeur de la nervure centrale
pin_d    = 5.3;    // passage de la vis M5
pin_x    = 24;     // position de l'axe des bobines devant la face avant
pin_z    = 1;      // hauteur de l'axe au-dessus du dessus du plateau
boss_r   = 7;      // bossage de la nervure autour de l'axe
bob_d    = 9;      // diamètre des bobines, sur lesquelles porte la sangle
bob_fl   = 14;     // diamètre du chapeau
screw_l  = 80;     // vis CHC M5×80 (tête cylindrique à six pans creux)
pocket   = 6;      // logement de la tête (Ø8,5 × 5) ou de l'écrou frein (5 mm) dans le chapeau
cap_l    = (screw_l - 5.5 - 2*elev_w - post_w)/2 + pocket;   // longueur d'un chapeau (≈ 9,25)
cone_l   = (bob_fl - bob_d)/2;                               // raccord conique à 45° entre bobine et chapeau

// --- Avant du plateau : plancher sous les bobines, puis deux couloirs qui tiennent les élévateurs à plat ---
tray_l   = 54;     // longueur devant la face avant
floor_t  = 1.8;    // plancher sous les bobines (la boucle passe entre la bobine et lui)
tray_t   = 3;      // fond des couloirs
ch_x0    = pin_x + bob_fl/2 + 3;   // début des couloirs, juste devant les chapeaux
fence_t  = 3;      // épaisseur des joues
fence_z  = 5;      // hauteur des joues au-dessus du dessus du plateau
fence_y  = post_w/2 + elev_w + 0.5;   // face intérieure des joues extérieures

// --- Poulie (1 roulement 625ZZ, axe M5) ---
pul_r   = 13;
pul_w   = 10;
cord_d  = 2;       // cordelette de 2 mm
axle_d  = 5.3;     // passage de la vis M5 (CHC M5×60 à tige partiellement filetée : le roulement porte sur la partie lisse)

// --- Cible articulée à l'avant du plateau, verrouillée d'équerre quand elle est relevée ---
// Relevée et poussée vers le bas, sa languette se coince entre la face avant du plateau et une
// lèvre inclinée : elle ne peut basculer ni en avant ni en arrière. Pour la rabattre, on la soulève
// de `lift` (les charnons ont une lumière), puis on la couche sur le plateau.
tg_t      = 3;     // épaisseur de la plaque
tg_w      = 84;    // largeur de la partie haute
tg_up     = 90;    // hauteur au-dessus de l'axe de charnière
tg_wide_z = 11;    // la plaque s'élargit au-dessus des oreilles
hinge_x   = 3.5;   // axe de charnière : en avant de la face avant du plateau…
hinge_z   = 4;     // …et au-dessus de son dessus. hinge_z - hinge_x = jeu de la cible rabattue (0,5)
ear_t     = 6;     // oreilles du plateau
ear_r     = 4;
knuckle_w = 7;     // charnons de la cible
knuckle_r = 3.5;
hinge_d   = 3.4;   // lumière des charnons, pour la moitié lisse de la goupille Ø3
ear_d     = 3.0;   // trou des oreilles, pour une goupille cannelée Ø3 × 12 (DIN 1474) : sa moitié cannelée
                   // mord dans l'oreille et ne ressort pas ; sa moitié lisse sert d'axe à la cible.
                   // Les lumières des charnons sont borgnes côté intérieur : la goupille ne peut pas non plus rentrer.
lift      = 5.5;   // course de soulèvement pour déverrouiller
flap_h    = 5.5;   // languette de verrouillage, sous le dessus du plateau
lip_top   = 1.5;   // sommet de la lèvre, sous le dessus du plateau
lip_y0    = post_w/2 + 1;    // la lèvre court de la nervure centrale…
lip_y1    = 28;              // …jusqu'avant les charnons
mire_z    = 45;    // hauteur de la mire gravée : viser toujours le trait horizontal
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

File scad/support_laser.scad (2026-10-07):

// ============================================================
//  Support du télémètre laser, côté voile — reprise de votre « TEST.stl ».
//
//  Même principe : le télémètre est couché dans une auge ouverte à l'avant ; sous l'avant,
//  un bec plat descend sous le fond et porte une encoche. La suspente passe dans l'encoche,
//  sa patte d'attache, trop grosse, bute contre le bec : sous 5 kg, la suspente reste dans
//  l'axe du faisceau. Lecture du laser + constante = longueur de la suspente.
//
//  Ce qui change par rapport à TEST.stl :
//   - cotes du télémètre en paramètres : largeur, longueur, épaisseur ;
//   - parois moins hautes que le télémètre (moins_epais), pour le saisir et atteindre ses boutons ;
//   - dégagement réglable dans une paroi pour les boutons placés sur le côté ;
//   - encoche de 3 mm, entrée en V, fond rond ; deux rainures pour un élastique, trou de dragonne.
//  Le bec garde strictement la forme de TEST.stl (4 mm, rien ne dépasse derrière lui).
//
//  Repère : y = sens du faisceau, face arrière du support en y = 0 ; z vers le haut, dessous
//  du fond en z = 0. Le bec est à l'avant (y = len), ses faces sont perpendiculaires au faisceau.
//  S'imprime debout sur la face avant du bec, sans support.
// ============================================================

// --- Télémètre : à mesurer au pied à coulisse (valeurs reprises de TEST.stl) ---
laser_w = 34.5;    // largeur
laser_l = 78.5;    // longueur
laser_h = 18;      // épaisseur
fit     = 0.5;     // jeu en largeur et en longueur
moins_epais = 3;   // les parois s'arrêtent à cette hauteur sous le dessus du télémètre

// --- Boutons sur le côté du télémètre : la paroi est abaissée en face d'eux ---
btn_cote = 0;      // 0 : aucun ; 1 : côté droit (x grand) ; -1 : côté gauche ; 2 : les deux
btn_y0   = 20;     // début du dégagement, depuis la face arrière du télémètre
btn_len  = 25;     // longueur du dégagement
btn_h    = 4;      // hauteur de paroi conservée sous le dégagement

// --- Auge ---
wall    = 3;       // parois
floor_t = 3;       // fond
r_ext   = 2;       // arrondi des arêtes du dessus et de l'arête arrière du dessous (comme TEST.stl)

// --- Bec et encoche (le bec reprend les 5 kg de la suspente) ---
bec_t    = 4;      // épaisseur du bec, comme sur TEST.stl
bec_drop = 11;     // descente du bec sous le fond
bec_bas  = 14;     // largeur du bec en bas
slit_w   = 3;      // largeur de l'encoche : la suspente passe, la patte (ou son nœud) non
slit_d   = 2.5;    // profondeur de la partie droite de l'encoche, au-dessus du V d'entrée
v_w      = 7;      // V d'entrée : largeur en bas…
v_d      = 2;      // …et profondeur

// --- Divers ---
elastique = true;  // deux rainures autour du support pour un élastique qui tient le télémètre
el_w = 3; el_d = 1;
el_pos = [0.3, 0.72];   // position des rainures, en fraction de la longueur
drag = 4;          // trou de dragonne dans la face arrière

// --- Valeurs dérivées ---
W      = laser_w + fit;
L      = laser_l + fit;
tray_w = W + 2*wall;
len    = wall + L;                     // face avant du bec = face avant du télémètre, au jeu près
wall_h = laser_h - moins_epais;
H      = floor_t + wall_h;
cx     = tray_w/2;                     // axe du faisceau et de l'encoche

$fn = 48;

module prism_y(y0, w) { translate([0, y0 + w, 0]) rotate([90, 0, 0]) linear_extrude(w) children(); }

module bec_profil() polygon([[0, 0], [tray_w, 0], [cx + bec_bas/2, -bec_drop], [cx - bec_bas/2, -bec_drop]]);

module encoche_profil() {
    zb = -bec_drop;
    polygon([[cx - v_w/2, zb - 1], [cx + v_w/2, zb - 1], [cx + slit_w/2, zb + v_d], [cx - slit_w/2, zb + v_d]]);
    translate([cx - slit_w/2, zb + v_d - 0.1]) square([slit_w, slit_d + 0.1]);
    translate([cx, zb + v_d + slit_d]) circle(d = slit_w, $fn = 24);
}

module bec() {
    difference() {
        prism_y(len - bec_t, bec_t) bec_profil();                                       // plaque
        prism_y(len - bec_t - 1, bec_t + 2) encoche_profil();                           // encoche
    }
}

// Bloc de l'auge, arrondi comme TEST.stl : les deux arêtes du dessus (le long du faisceau) et
// l'arête arrière du dessous. Les arêtes verticales restent vives, pour que le bec, qui prend
// toute la largeur, affleure les flancs sans lèvre.
module bloc() {
    intersection() {
        rotate([90, 0, 0]) translate([0, 0, -len]) linear_extrude(len) hull() {          // profil x-z : dessus arrondi
            square([tray_w, H - r_ext]);
            for (x = [r_ext, tray_w - r_ext]) translate([x, H - r_ext]) circle(r_ext);
        }
        rotate([90, 0, 90]) linear_extrude(tray_w) hull() {                              // profil y-z : arête arrière-dessous arrondie
            translate([r_ext, 0]) square([len - r_ext, H]);
            translate([0, r_ext]) square([len, H - r_ext]);
            translate([r_ext, r_ext]) circle(r_ext);
        }
    }
}

module support_laser() {
    difference() {
        union() {
            bloc();
            bec();
        }
        translate([wall, wall, floor_t]) cube([W, L + 1, H]);                                // logement, ouvert à l'avant
        // dégagement des boutons latéraux
        for (s = btn_cote == 2 ? [-1, 1] : btn_cote == 0 ? [] : [btn_cote])
            translate([s > 0 ? tray_w - wall - 1 : -1, wall + btn_y0, floor_t + btn_h]) cube([wall + 2, btn_len, H]);
        // trou de dragonne dans la face arrière
        translate([cx, -1, floor_t + wall_h/2]) rotate([-90, 0, 0]) cylinder(d = drag, h = wall + 2);
        // rainures pour l'élastique, autour des parois et du fond
        if (elastique) for (f = el_pos) translate([0, f*len - el_w/2, 0]) difference() {
            translate([-1, 0, -1]) cube([tray_w + 2, el_w, H + 2]);
            translate([el_d, -1, el_d]) cube([tray_w - 2*el_d, el_w + 2, H + 2]);
        }
    }
}

// orientation d'impression : debout sur la face avant du bec (la face qui regarde la cible)
translate([0, 0, len]) rotate([-90, 0, 0]) support_laser();

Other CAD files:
stl/support_laser_bosch_glm50.stl
stl/support_laser_leica_d1.stl
stl/bobine_ecrou.stl
stl/bobine_tete.stl
stl/cible.stl
stl/entretoises_grappe.stl
stl/poulie.stl

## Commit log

2026-10-07 Banc de calage parapente : modèles, STL, images, outils et site
    [banc.scad, banc_149mm.scad, bobine_ecrou.stl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]
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2026-10-07 Support du laser : encoche de 3 mm, matière recommandée ; dépôt public
    [support_laser.scad, support_laser.stl]
2026-10-07 Une pièce par fichier STL : suppression de petites_pieces.stl
    [banc.scad, petites_pieces.stl]
2026-10-07 Page simplifiée : README court, support du laser en bannière, achats AliExpress seulement ; détails dans NOTES.md
2026-10-07 Page plus courte, langage de pilote, encoche du support visible en bannière
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2026-10-07 Support du laser : bec de TEST.stl, une version par télémètre, offset 21 mm
    - Le bec reprend strictement la forme de TEST.stl (4 mm) : la bande de renfort,
    qui débordait sous le fond, est retirée. Encoche de 3 mm conservée.
    - Une version du support par télémètre Leica DISTO et Bosch à moins de 500 €,
    aux cotes constructeur (outils/lasers.json) : 14 STL, une image chacune, et le
    tableau des versions écrit dans les deux README par outils/generer_stl.mjs,
    avec le repère de mesure (avant ou arrière seulement).
    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
    [support_laser.scad, support_laser.stl, support_laser_bosch_glm100_150.stl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]
2026-10-07 Site bilingue (anglais à la racine, français dans fr/) et habillage WeFlare
    outils/site.py construit les deux pages depuis README.en.md et README.md, avec le
    sélecteur de langue, les balises d'aperçu de lien et la feuille commune des outils
    WeFlare (weflare.css, weflare.svg, weflare-mark.svg).
2026-10-07 Nouveau logo WeFlare sur la page de présentation
    Le logo de l'en-tête et du pied de page est le nouveau logo WeFlare : voile
    orange, suspentes aux bouts arrondis, « We » gras et « Flare » demi-gras.
    L'icône de l'onglet est son monogramme sur fond nuit.
2026-10-07 Support du laser : arrondis comme TEST.stl, plus de lèvre au bec
    Les arêtes verticales du bloc étaient arrondies ; le bec, qui prend toute la
    largeur, dépassait des coins arrondis et formait une lèvre jusqu'à l'encoche.
    Le bloc reprend les arrondis de TEST.stl (les deux arêtes du dessus et l'arête
    arrière du dessous), les arêtes verticales sont vives et le bec affleure.
    [support_laser.scad, support_laser_bosch_glm100_150.stl, support_laser_bosch_glm40.stl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]
2026-10-07 Page de présentation : Wing Trim parmi les autres outils gratuits, sous-titre sans la poche à eau
2026-10-07 Calibre des goupilles, goupilles moletées, socle en nylon chez JLC3DP
    - calibre_goupilles : barrette d'essai à imprimer avant le banc, avec les
    trous à six pans des goupilles en huit cotes (4,85 à 5,20 et 2,85 à 3,20 mm)
    - achats : goupilles moletées à un bout à la place des goupilles lisses,
    qui ne tiennent que si le trou sort à quelques centièmes près
    - JLC3DP : le socle passe en nylon, il serre la goupille de la poulie ;
    seule la cible reste en résine
    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
    [banc.scad, calibre_goupilles.scad, calibre_goupilles.stl]
2026-10-07 Achats en Europe : un lien par pièce, visserie sur un seul site
    - README : tableau « La même chose en Europe », toute la visserie chez
    visseriefixations.fr, roues chez 3delectroshop.fr
    - NOTES : les vis et les écrous passent de marleva.net à visseriefixations.fr,
    avec ce que la recherche du 8 octobre a écarté et pourquoi
2026-10-08 Goupilles cannelées dans des trous ronds, à la place des trous à six pans
    - socle et coulisseau : les trous des goupilles sont ronds, au diamètre
    nominal (5,00 et 3,00), comme le prévoit la norme des goupilles cannelées
    - axe de poulie : goupille cannelée DIN 1472 de 5 × 30, bout cannelé 7 mm
    sous le flanc, pour que les cannelures s'arrêtent avant le roulement
    - charnières : goupilles cannelées DIN 1472 de 3 × 12
    - calibre : trous ronds, de 4,90 à 5,25 et de 2,90 à 3,25 mm
    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
    [banc.scad, calibre_goupilles.scad, calibre_goupilles.stl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]
2026-10-08 Vis et écrous frein à la place des goupilles, contrôle avant impression
    - axe de poulie : vis CHC M5×40 et écrou frein, noyés dans les crochets
    - charnières de la cible : vis M3×12 et écrou frein logé dans l'oreille
    - trous de passage Ø5,3 et Ø3,3 ; le calibre des goupilles est supprimé
    - contrôle avant impression : axe de poulie descendu de 1 mm et oreilles
    relevées de 0,5 mm pour épaissir deux parois ; maillages, interférences,
    pontages, parois et efforts sous 5 kg notés dans NOTES.md
    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
    [banc.scad, calibre_goupilles.scad, calibre_goupilles.stl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]
2026-10-08 WeFlare devient WeSoar : nom, logo et fichiers d'habillage de la page
    L'école s'appelle WeSoar depuis le 8 octobre 2026. La page de présentation porte le nouveau nom et le nouveau logo
    (outils/wesoar.svg, d'une seule couleur ; outils/wesoar-mark.svg pour l'onglet). La feuille commune devient
    outils/wesoar.css : le logo, plus haut, y gagne la hauteur qu'il faut pour que le mot garde sa taille.
    Les adresses en weflare.fr ne changent pas encore.
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
